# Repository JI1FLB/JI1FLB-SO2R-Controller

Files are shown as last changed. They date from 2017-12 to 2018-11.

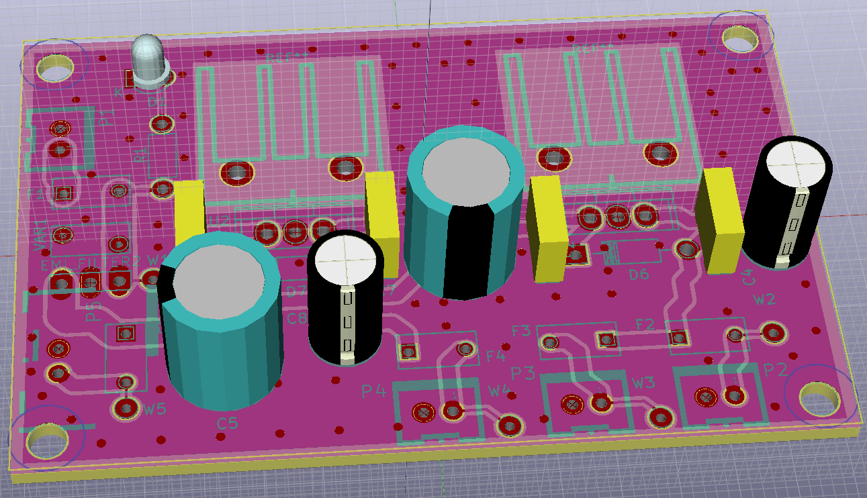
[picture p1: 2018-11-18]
CAD_data/SO2R-Power-unit-v0r0/SO2R-Power-unit-PCB-v0r0.png

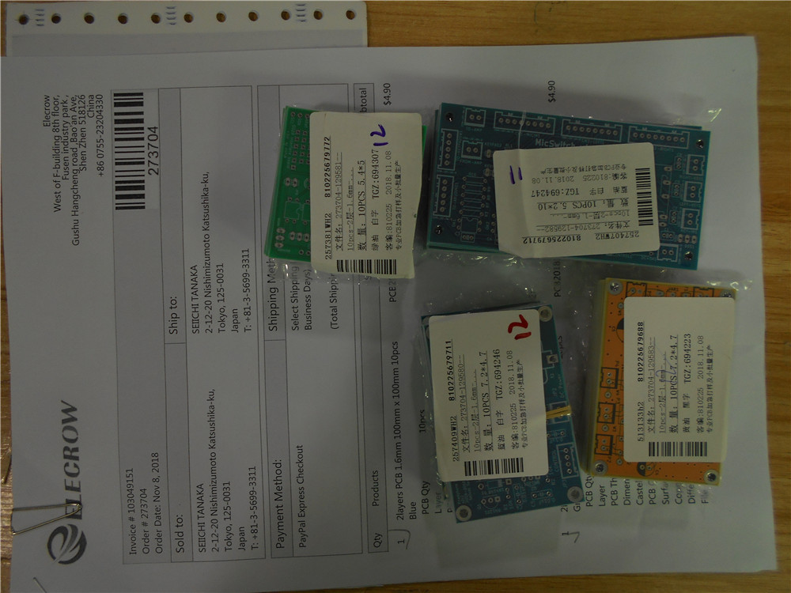
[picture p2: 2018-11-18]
CAD_data/MicSwitch-IF-v1r5/MicSwitch-IF-v1r5製造ファイル/273704.jpg

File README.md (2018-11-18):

# JI1FLB-SO2R-Controller

This JI1FLB SO2R box (controller) is a tool for amateur radio contest and works with OTRPS protocol.
This device controls two amateur radio rigs and is programmed with Arduino UNO sketch.
Hardware was composed of circuits that are easily available at electronic parts stores.
In addition, each circuit is designed to PCB to ensure ease of manufacture and product stability.

This JI1FLB　SO2R box (controller) provides software and hardware as freeware subject to non-commercial use.
Hardware PCB board is scheduled to provide KiCAD data subject to non-commercial use after completion of reprocessing.
I will supply the PCB to those who need it, with shipping fee and very cheap actual expenses. 
However, some consideration is required when installing some parts.

このJI1FLB　SO2Rボックス（コントローラ）は、アマチュア無線コンテスト用ツールでOTRPSプロトコロルで動作します。
この装置は、2台のアマチュア無線リグをコントロールするもので、ArduinoUNOのスケッチでプログラムされています。
ハードウェアは、電子パーツ店で容易に入手可能な部品で回路を構成しました。
また、各回路は、製作の容易性、製品の安定性を確保するため、PCB化を図っています。

このJI1FLB　SO2Rボックス（コントローラ）は、非商用利用を条件にソフトウェアとハードウェアをフリーウェアとして提供します。
ハードウェアのPCB基板は、KiCADデータを再作が完了後に、非商用利用を条件に提供する予定です。
私は、PCBを必要な方に、送料と非常に安価な実費で供給します。ただし、一部の部品を取り付け際に若干の考慮が必要です。

2018/11/18 Seiichi Tanaka 田中盛一

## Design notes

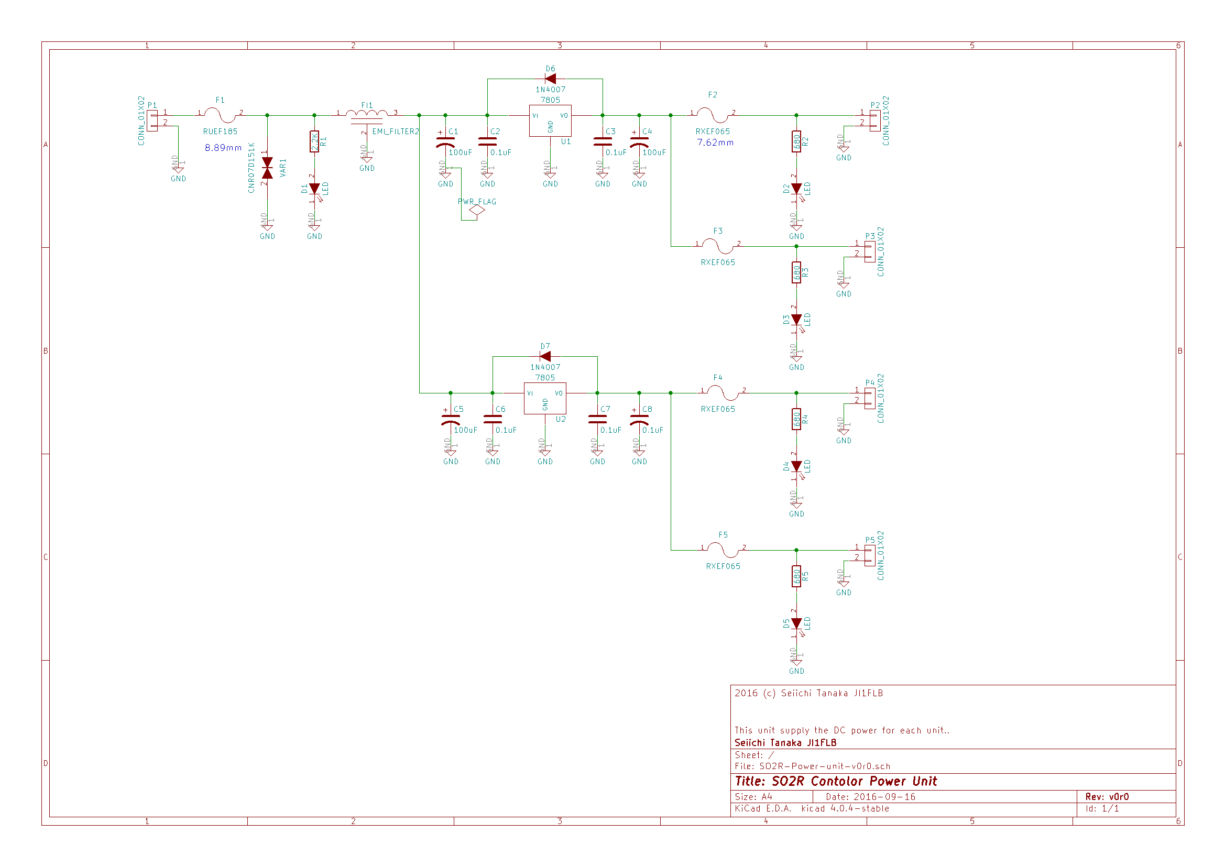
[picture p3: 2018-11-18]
CAD_data/SO2R-Power-unit-v0r0/SO2R-contolor-PU-v0r0.png

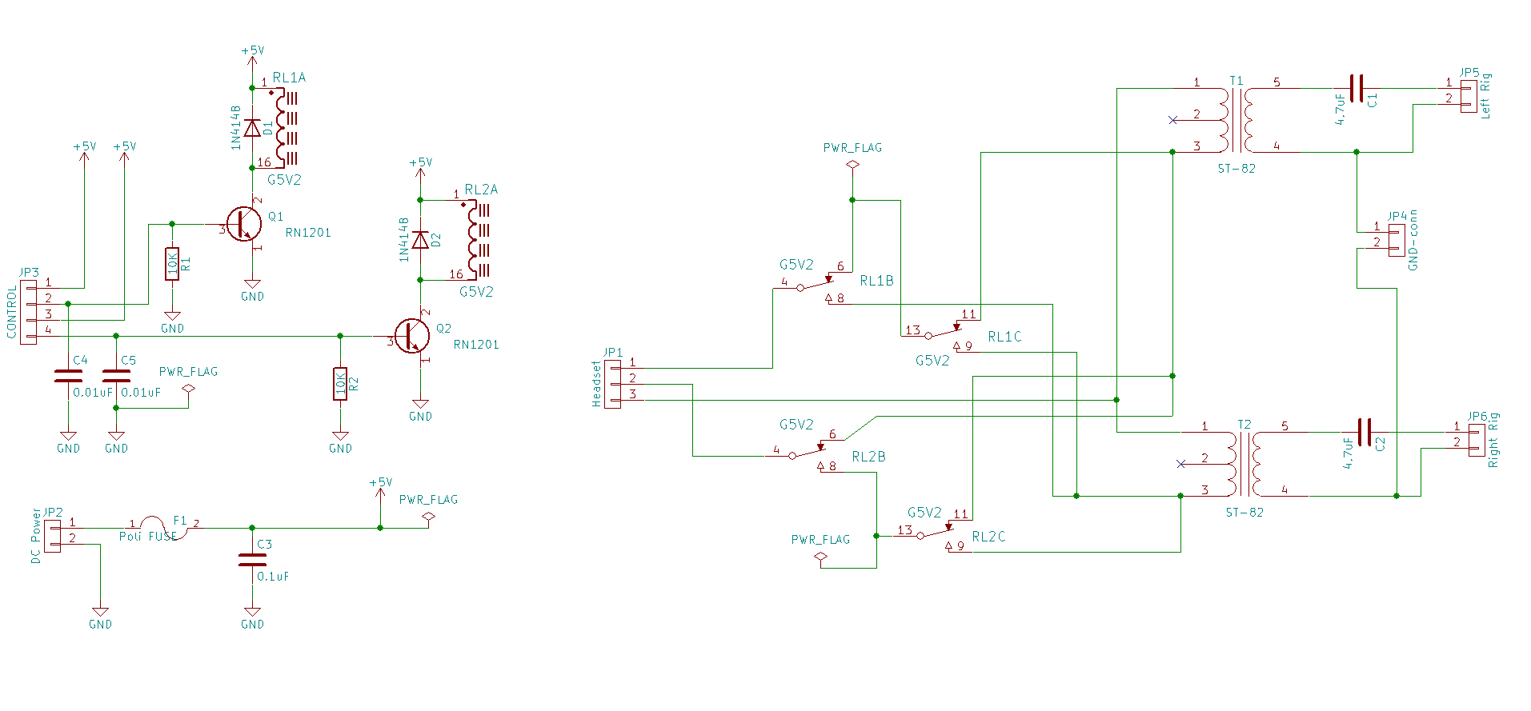
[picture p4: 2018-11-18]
CAD_data/Headphone-controler-v2r2/Headphone-controler-v2r2.png

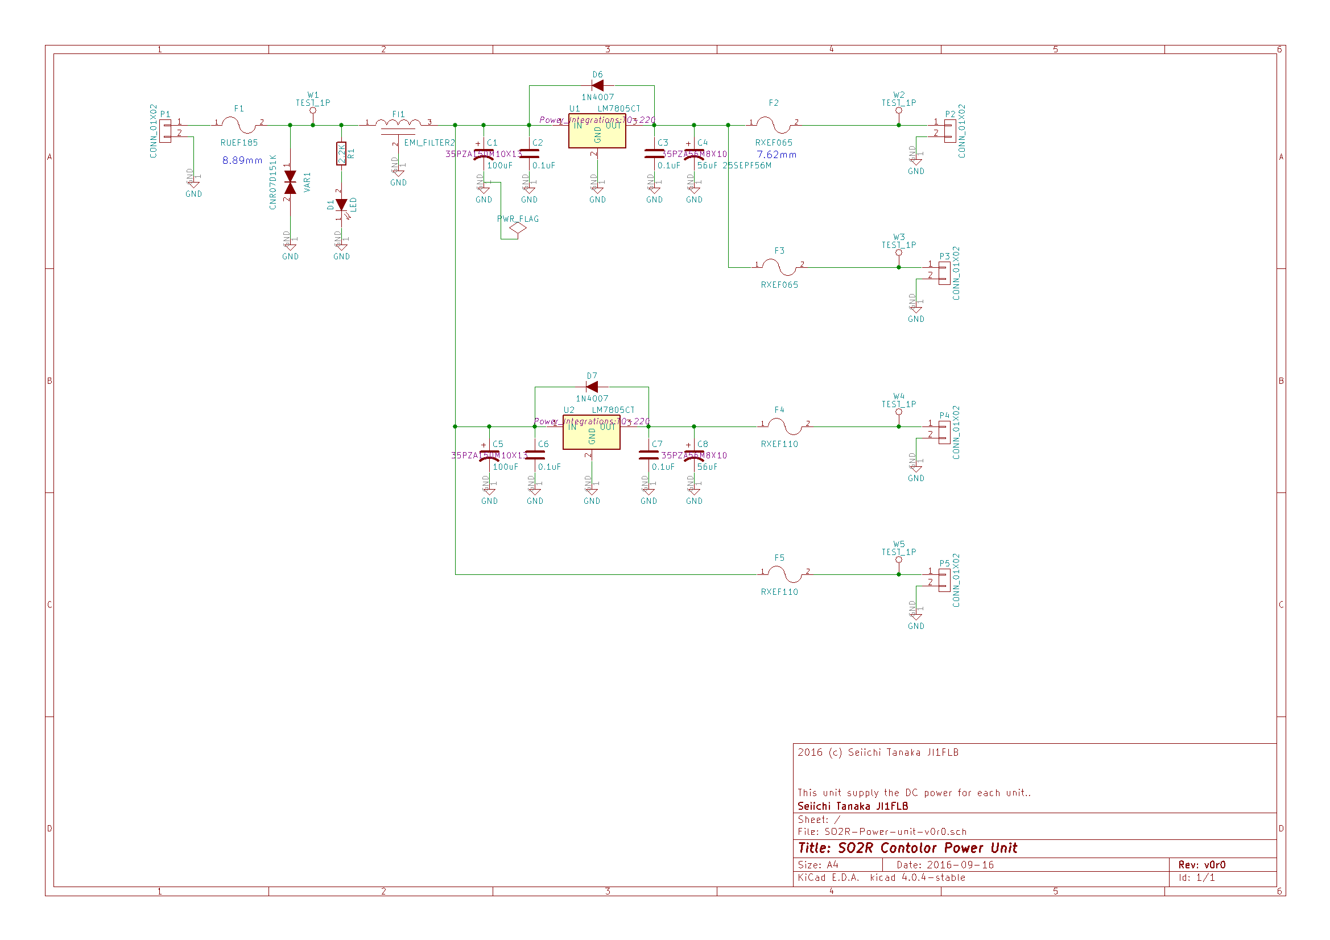
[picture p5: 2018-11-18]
CAD_data/SO2R-Power-unit-v0r0/SO2R-contolor-PU-v0r0-fixed.png

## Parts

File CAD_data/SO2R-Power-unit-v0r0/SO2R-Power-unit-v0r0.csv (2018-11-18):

ID | 参照記号 | パッケージ | 数 | 名称 | Supplier and ref
1 | C1,C5 | C_Radial_D10_L13_P5 | 2 | 100uF
2 | C2,C3,C6,C7 | C_Rect_L7_W2_P5 | 4 | 0.1uF
3 | D1 | LED-3MM | 1 | LED
4 | D6,D7 | Diode_DO-41_SOD81_Horizontal_RM10 | 2 | 1N4007
5 | F1 | C_Rect_L7_W3.5_P5 | 1 | RUEF185
6 | F2,F3 | C_Rect_L7_W3.5_P5 | 2 | RXEF065
7 | F4,F5 | C_Rect_L7_W3.5_P5 | 2 | RXEF110
8 | P1,P2,P3,P4,P5 | CON-JST-B02B-XASK-1 | 5 | CONN_01X02
9 | U1,U2 | TO-220 | 2 | LM7805CT
10 | W1,W2,W3,W4,W5 | SolderWirePad_single_0-8mmDrill | 5 | TEST_1P
11 | VAR1 | RV_Disc_D7_W3.4_P5 | 1 | CNR07D151K
12 | C4 | C_Radial_D6.3_L11.2_P2.5 | 1 | 56uF 25SEPF56M
13 | C8 | C_Radial_D6.3_L11.2_P2.5 | 1 | 56uF
14 | REF2,REF1 | Heatsink-16PB017 | 2 | Heatsink-16PB017
15 | R1 | Resistor_Horizontal_RM7mm | 1 | 2.2K
16 | FI1 | EMIFILTER | 1 | EMI_FILTER2
17 | REF**,REF**,REF**,REF** | MountingHole_3.2mm_M3_ISO7380_Pad | 4 | MountingHole_3.2mm_M3_ISO7380_Pad

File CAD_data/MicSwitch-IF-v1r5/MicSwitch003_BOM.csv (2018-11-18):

ID | 参�?記号 | パッケージ | 数 | 名称 | Supplier and ref
1 | D1,D2,D3,D4,D5 | DO35-7 | 5 | 1N4148
2 | DSS1 | EMIFILTER | 1 | 0.01u
3 | DC+5V1,CONTROL1,KEY-IN1,LEFT-KEY1,RIGHT-KEY1,TO-AMP,FROM-AMP | CON-JST-B02B-XASK-1 | 7 | CON-JST-XA-2
4 | Q1 | TO220BV | 1 | 2SK4017
5 | R1 | 0207_7 | 1 | 33
6 | R2 | 0207_7 | 1 | 10K
7 | RL1,RL2,RL3,RL4,RL5 | 351 | 5 | 941H-2C-5D
8 | CN1-MICIN1,CN2-RIGHT1,CN3-LEFT1 | CON-JST-B08B-XASK-1 | 3 | CON-JST-XA-8
9 | KEYPAD2,KEYPAD1 | 1X02 | 2 | PINHD-1X2
10 | R3,R4 | 0207_7 | 2 | 1.5k
11 | R5 | 0207_7 | 1 | 2.2k
12 | R6 | 0207_7 | 1 | 4.7k
13 | OK1,OK2,OK3,OK4 | DIL04 | 4 | TLP222AF
14 | TO-ARUDINO1,TO-KEYPADSW1 | CON-JST-B05B-XASK-1 | 2 | CON-JST-XA-5
15 | R7,R8,R9,R10 | 0207_7 | 4 | 480
16 | C1,C2,C3,C4,C5,C6,C7,C8,C9 | C025-030X050 | 9 | 0.01
17 | REF**,REF**,REF**,REF** | MountingHole_3.2mm_M3 | 4 | MountingHole_3.2mm_M3

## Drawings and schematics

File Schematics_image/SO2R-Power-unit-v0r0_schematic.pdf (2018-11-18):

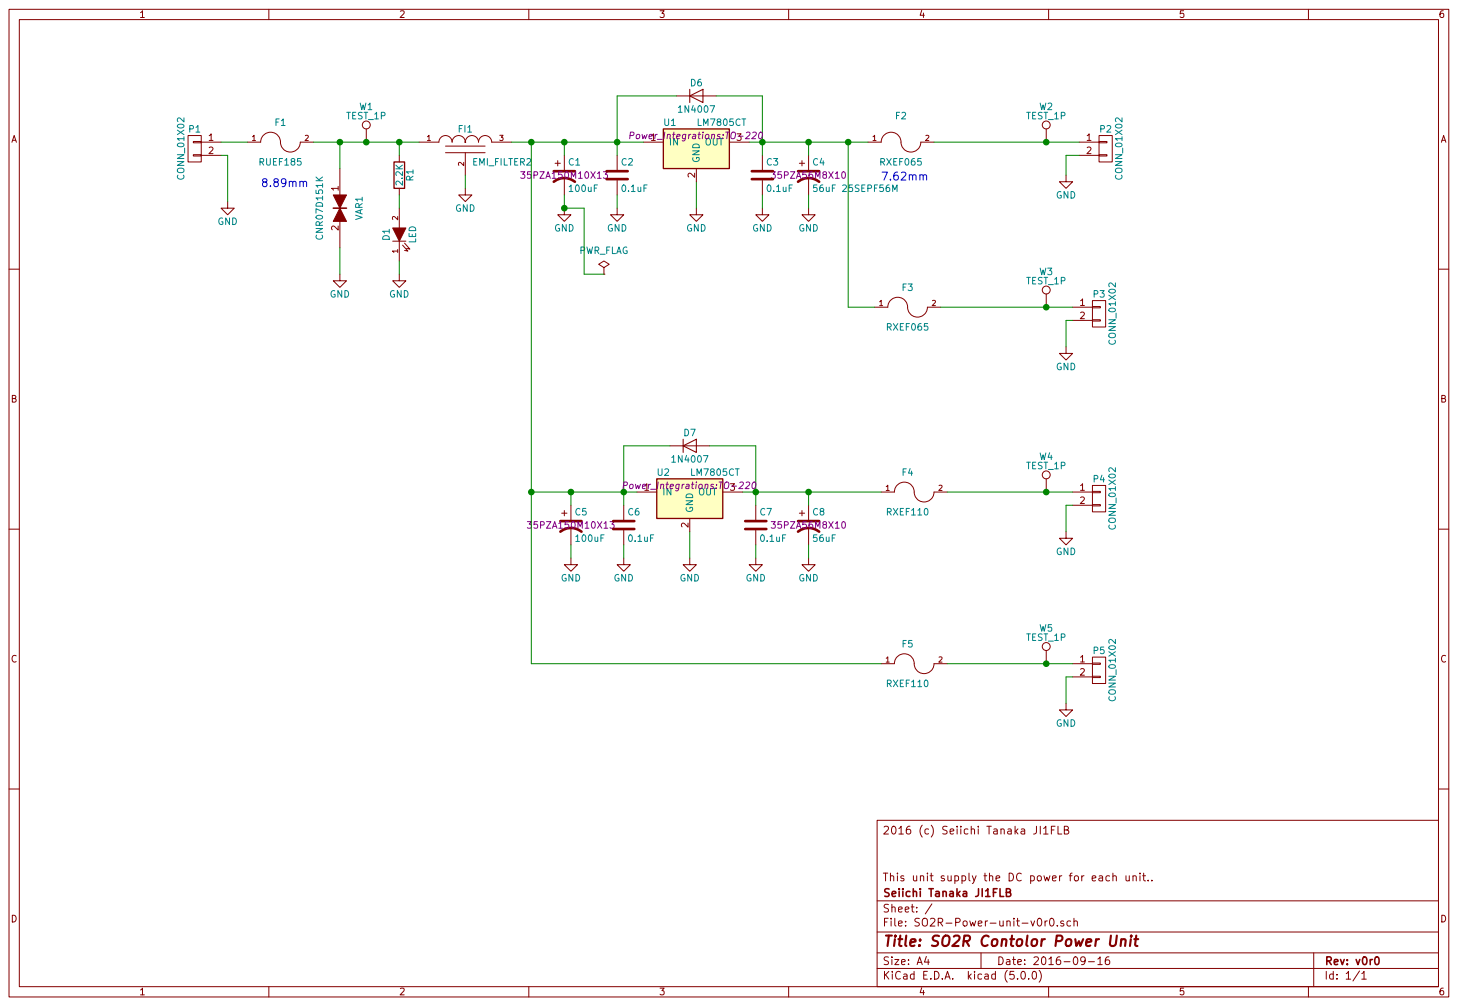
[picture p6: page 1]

1 2 D1 LED R1 2.2K GND GND GND GND GND GND GND GND GNDGND GND GND GND GND GND GND

This unit supply the DC power for each unit..
Id: 1/1 Title: SO2R Contolor Power Unit File: SO2R-Power-unit-v0r0.sch Sheet: / Seiichi Tanaka JI1FLB

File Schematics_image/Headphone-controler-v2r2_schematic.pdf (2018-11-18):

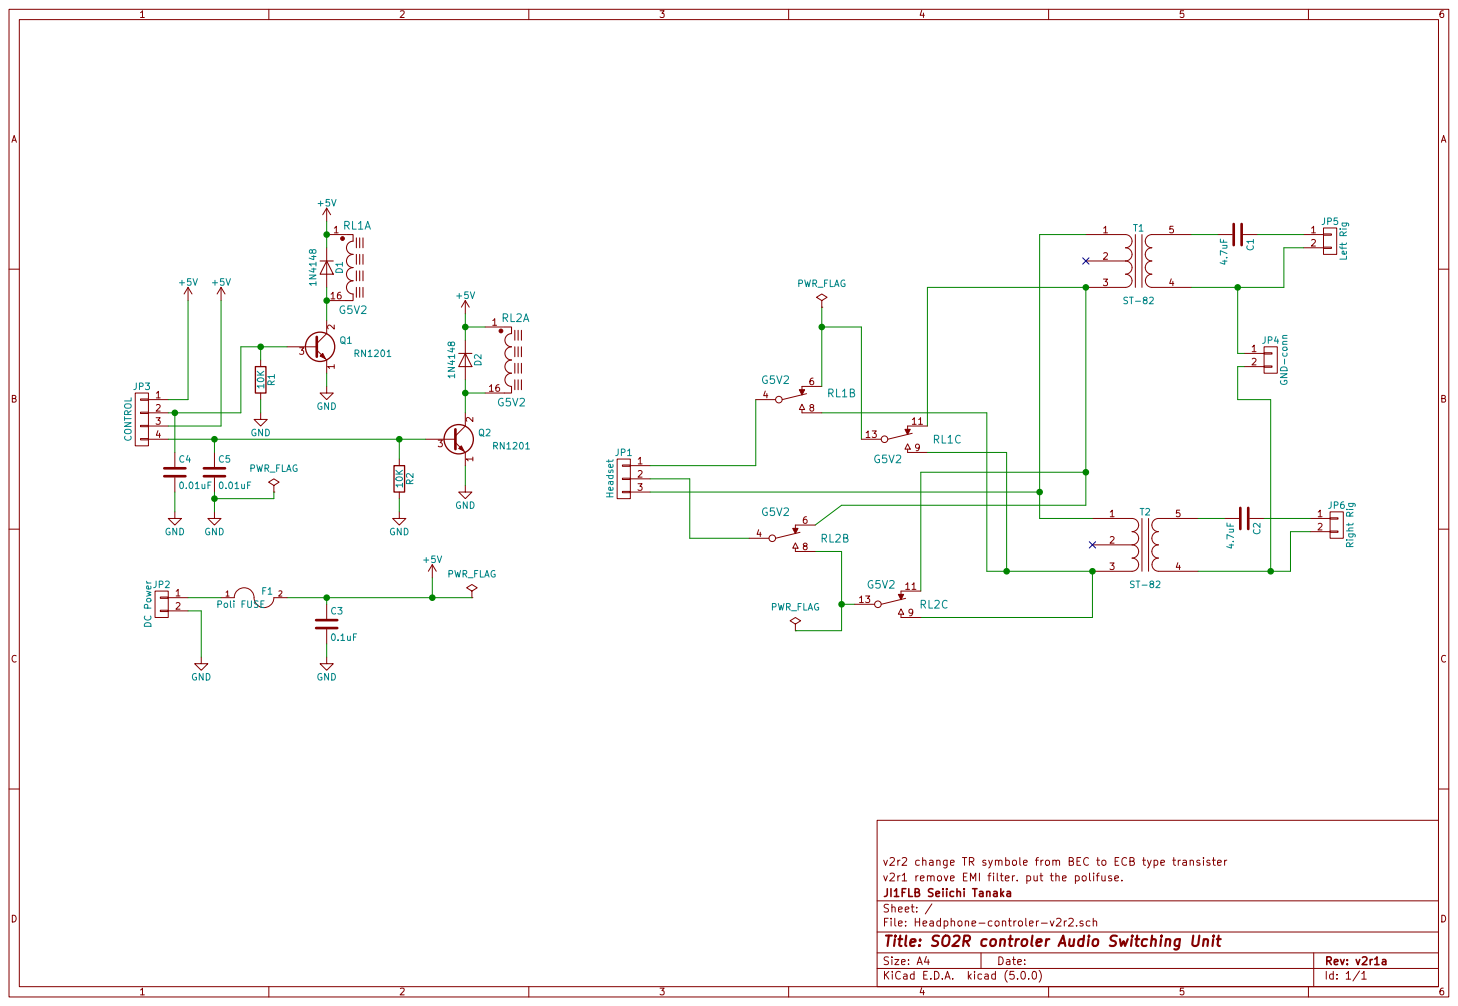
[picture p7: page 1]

v2r2 change TR symbole from BEC to ECB type transister
v2r1 remove EMI filter. put the polifuse.
File: Headphone-controler-v2r2.sch Sheet: / JI1FLB Seiichi Tanaka

Id: 1/1 Title: SO2R controler Audio Switching Unit

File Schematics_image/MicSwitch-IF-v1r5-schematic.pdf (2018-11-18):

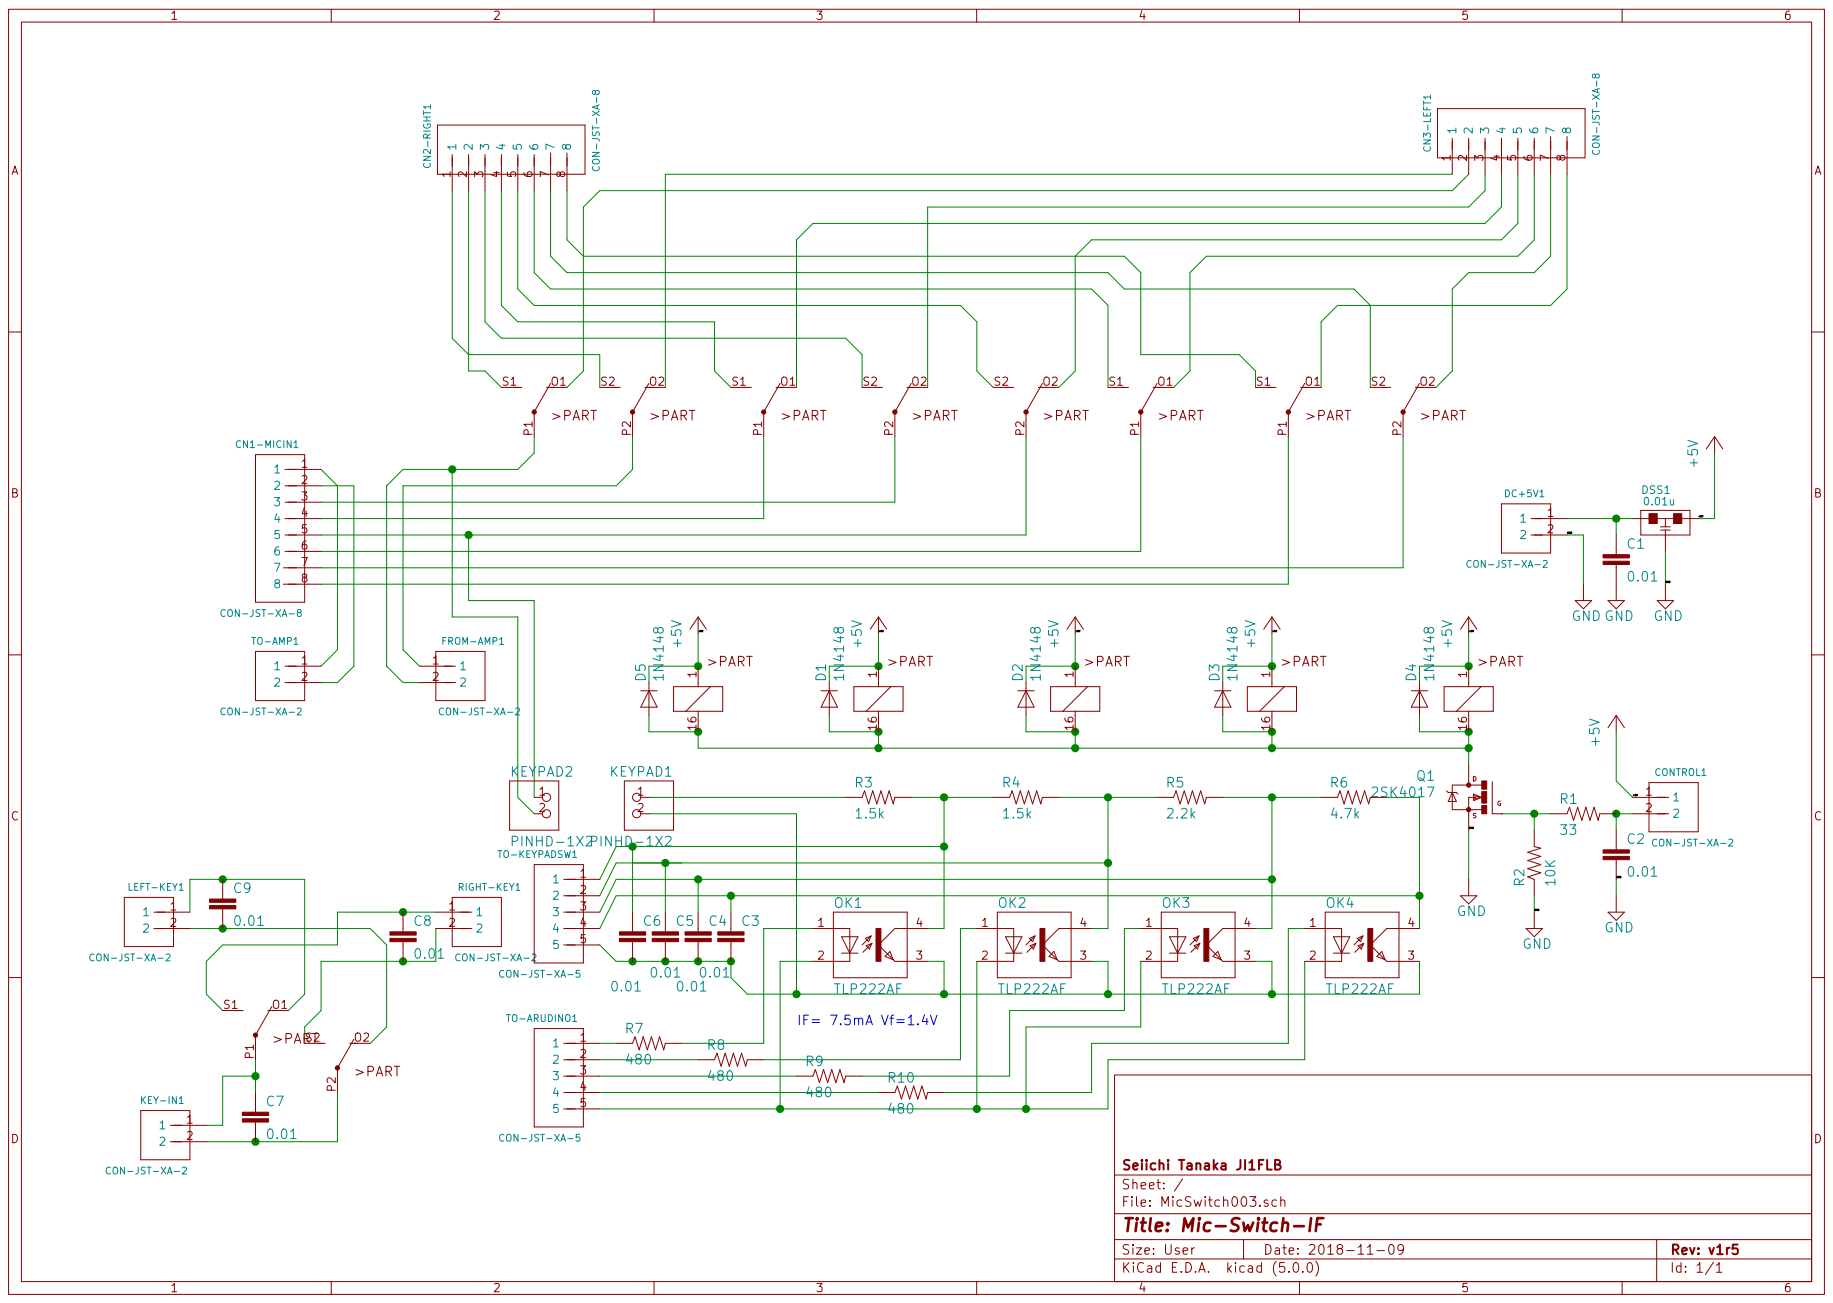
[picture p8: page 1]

File: MicSwitch003.sch Sheet: / Seiichi Tanaka JI1FLB

Id: 1/1 Title: Mic-Switch-IF

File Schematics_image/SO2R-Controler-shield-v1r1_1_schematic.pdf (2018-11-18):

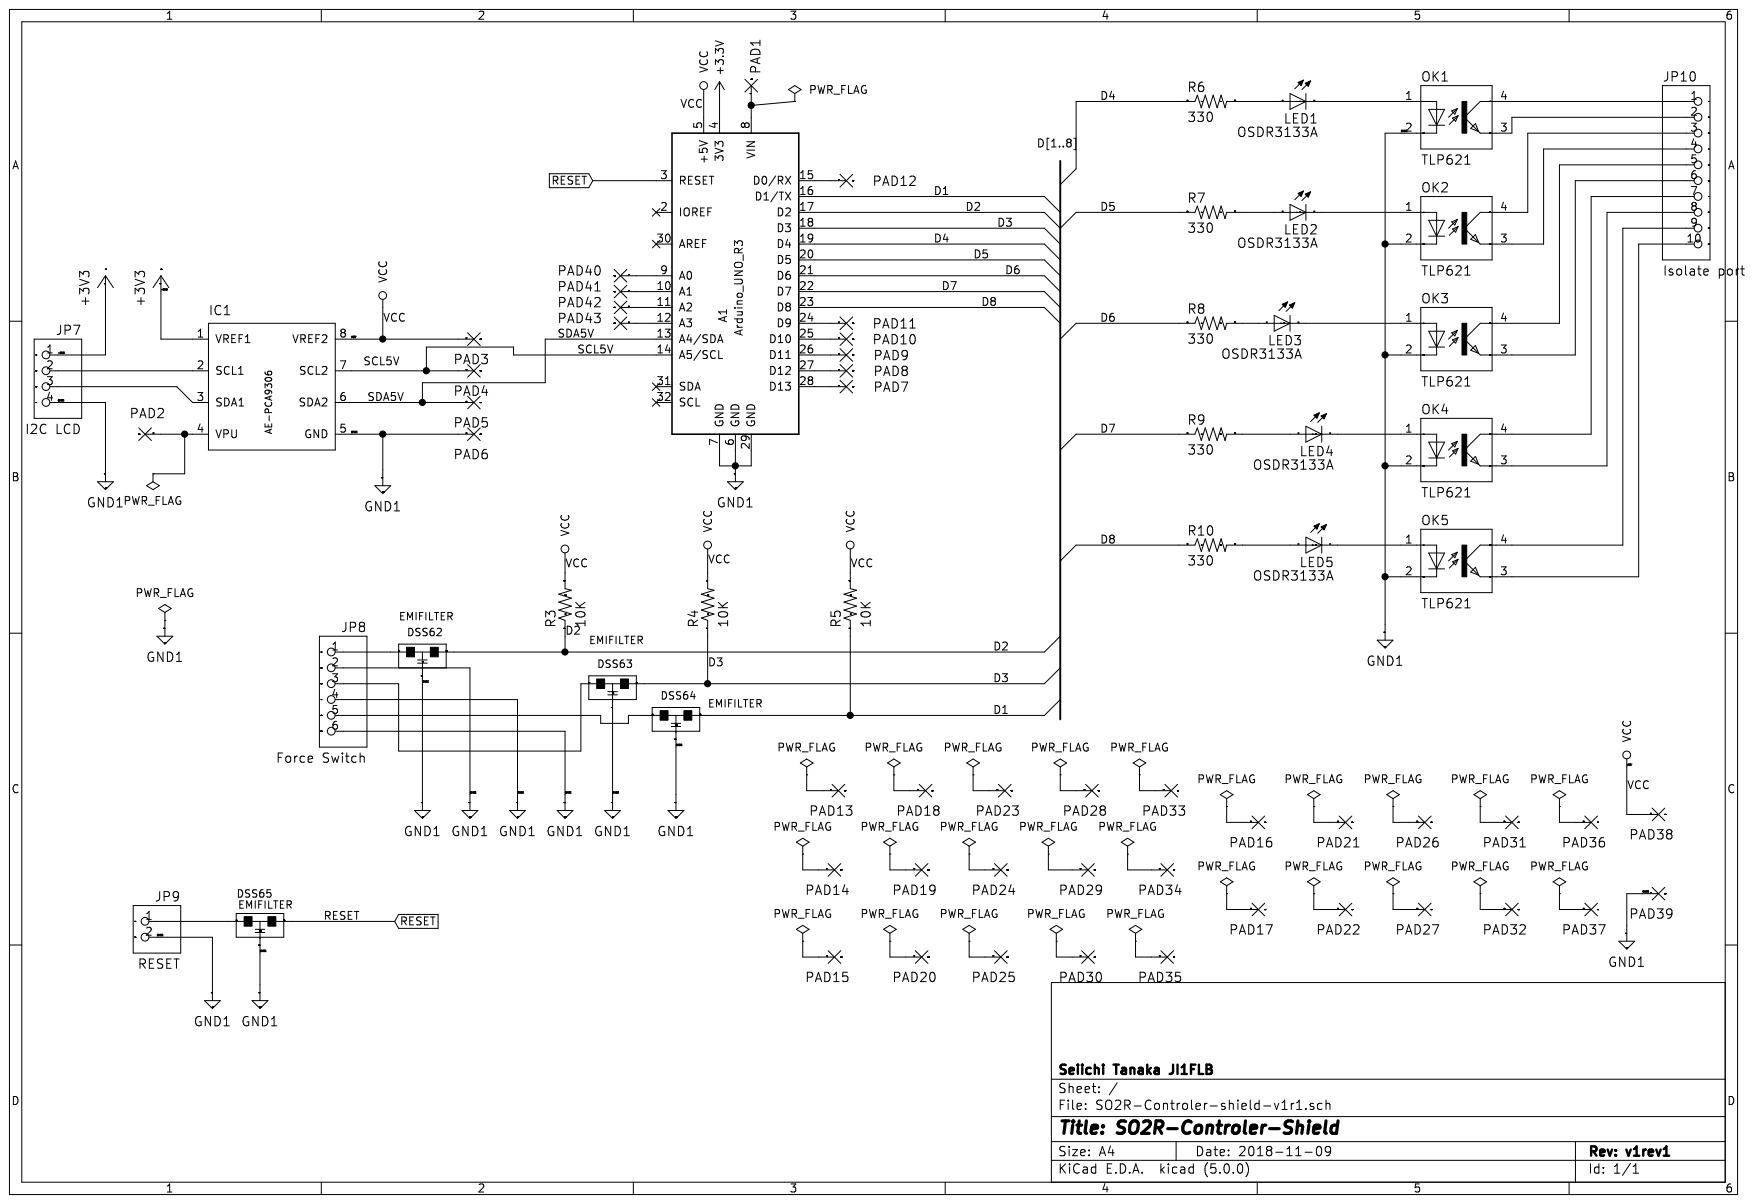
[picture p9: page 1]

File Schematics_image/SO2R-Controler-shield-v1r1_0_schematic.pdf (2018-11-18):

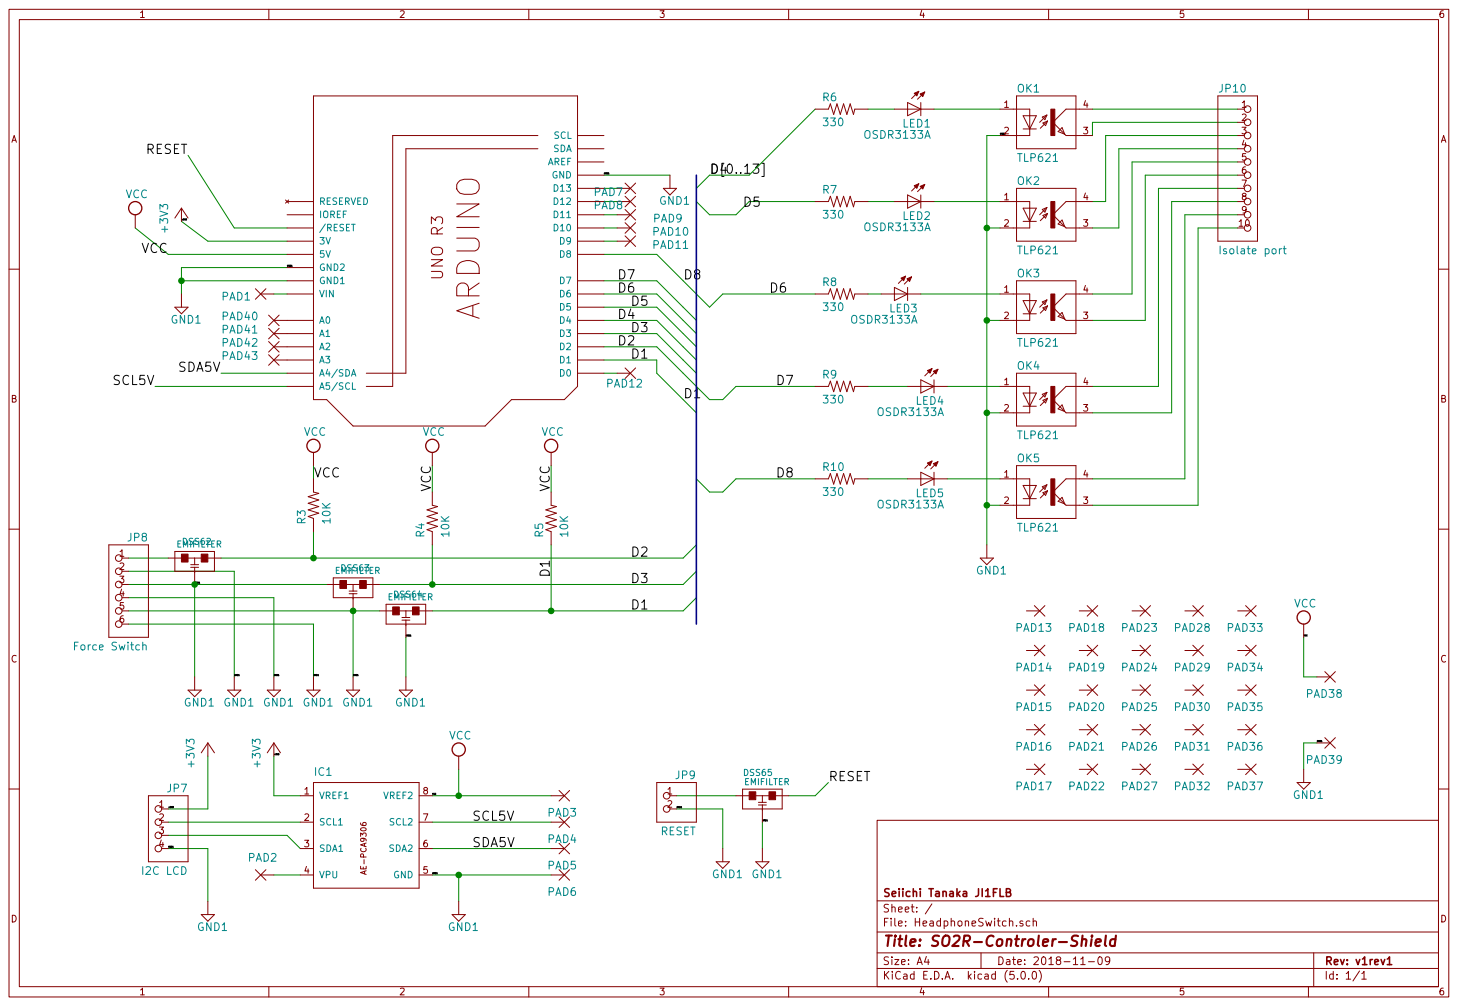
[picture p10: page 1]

File: HeadphoneSwitch.sch Sheet: / Seiichi Tanaka JI1FLB

Id: 1/1 Title: SO2R-Controler-Shield

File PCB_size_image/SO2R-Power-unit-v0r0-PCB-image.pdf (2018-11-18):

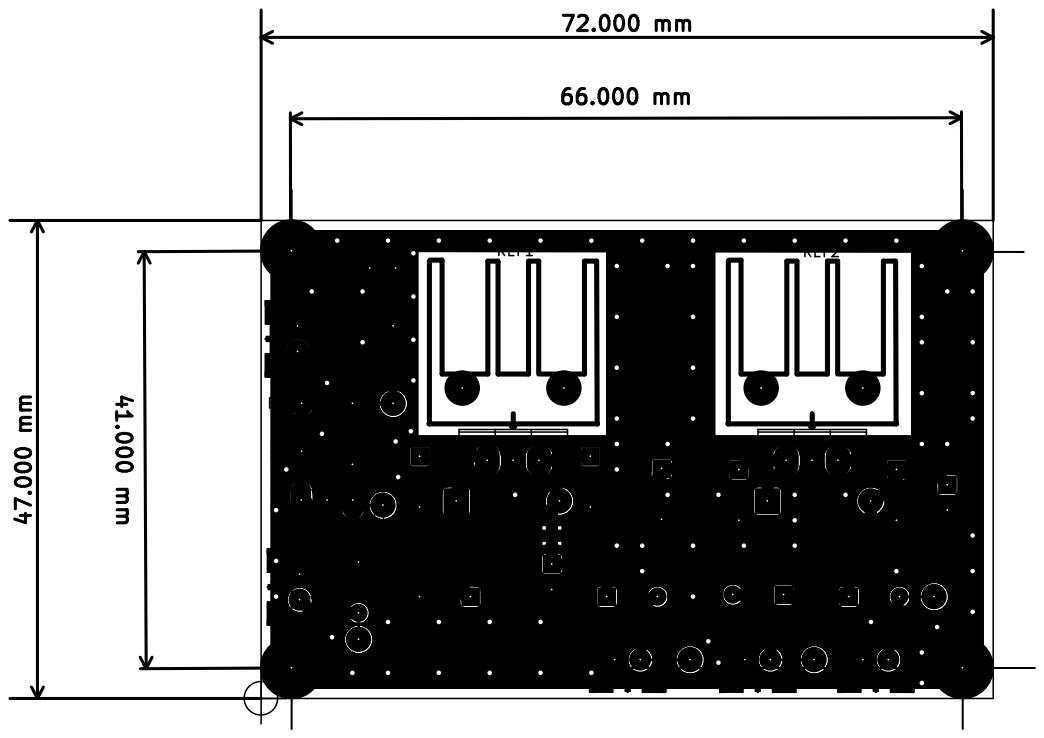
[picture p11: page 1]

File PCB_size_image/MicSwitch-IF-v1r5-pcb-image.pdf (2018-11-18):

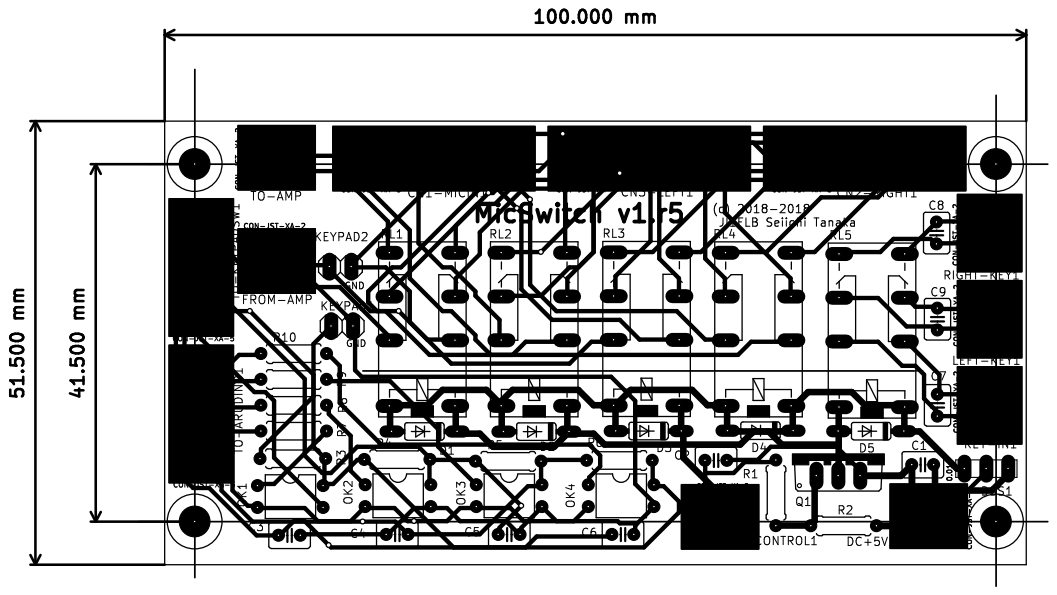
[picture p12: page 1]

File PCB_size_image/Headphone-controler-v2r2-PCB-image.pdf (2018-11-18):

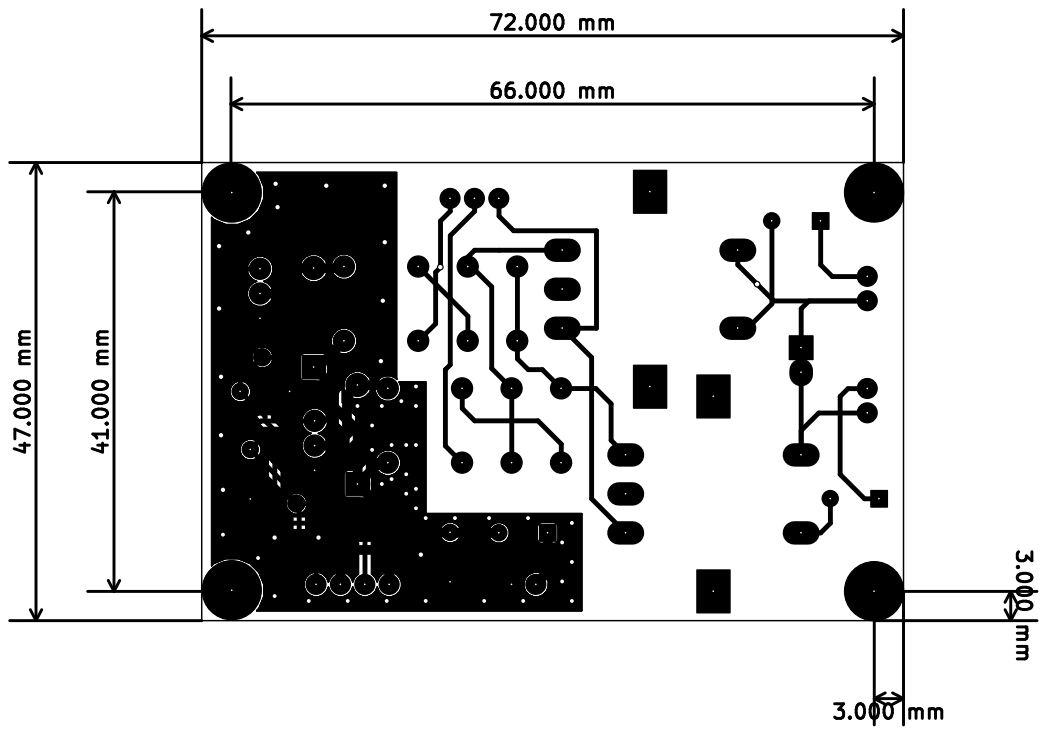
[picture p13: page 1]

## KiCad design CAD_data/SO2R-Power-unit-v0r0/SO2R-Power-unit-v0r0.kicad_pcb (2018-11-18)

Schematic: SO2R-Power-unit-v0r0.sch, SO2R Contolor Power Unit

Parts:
C1, C5: 100uF; C_Radial_D10_L13_P5
C2, C3, C6, C7: 0.1uF; C_Rect_L7_W2_P5
C4: 56uF 25SEPF56M; C_Radial_D6.3_L11.2_P2.5
C8: 56uF; C_Radial_D6.3_L11.2_P2.5
D1: LED; LED-3MM
D6, D7: 1N4007; Diode_DO-41_SOD81_Horizontal_RM10
F1: RUEF185; C_Rect_L7_W3.5_P5
F2, F3: RXEF065; C_Rect_L7_W3.5_P5
F4, F5: RXEF110; C_Rect_L7_W3.5_P5
FI1: EMI_FILTER2; EMIFILTER
P1, P2, P3, P4, P5: CONN_01X02; CON-JST-B02B-XASK-1
R1: 2.2K; Resistor_Horizontal_RM7mm
U1, U2: LM7805CT; TO-220
VAR1: CNR07D151K; RV_Disc_D7_W3.4_P5
W1, W2, W3, W4, W5: TEST_1P; SolderWirePad_single_0-8mmDrill

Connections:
GND: C1.2, C2.2, C3.2, C4.2, C5.2, C6.2, C7.2, C8.2, D1.1 (K), FI1.2 (GND), P1.2, P2.2, P3.2, P4.2, P5.2, U1.2 (GND), U2.2 (GND), VAR1.2
unnamed: C1.1, C2.1, C5.1, C6.1, D6.1, D7.1, F5.1, FI1.3 (VO), U1.1 (IN), U2.1 (IN)
unnamed: C3.1, C4.1, D6.2, F2.1, F3.1, U1.3 (OUT)
unnamed: C7.1, C8.1, D7.2, F4.1, U2.3 (OUT)
unnamed: D1.2 (A), R1.2
unnamed: F1.1, P1.1
unnamed: F1.2, FI1.1 (VI), R1.1, VAR1.1, W1.1
unnamed: F2.2, P2.1, W2.1
unnamed: F3.2, P3.1, W3.1
unnamed: F4.2, P4.1, W4.1
unnamed: F5.2, P5.1, W5.1

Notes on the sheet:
7.62mm
8.89mm

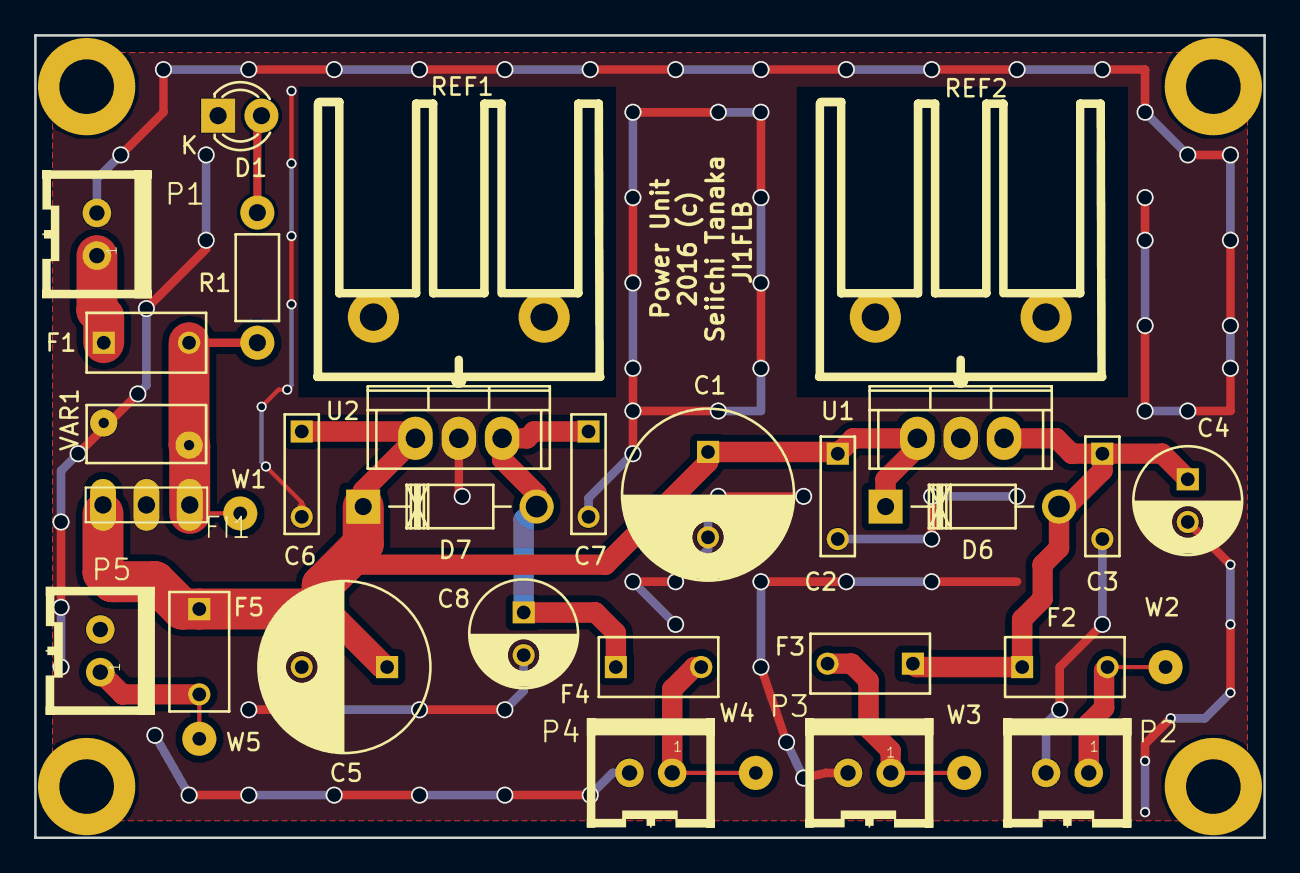
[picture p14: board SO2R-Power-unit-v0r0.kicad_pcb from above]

Board: 2 copper layers, 72.0 x 47.0 mm, 33 parts (0 on the bottom side), 11 nets.

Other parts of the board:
REF1, REF2: Heatsink-16PB017

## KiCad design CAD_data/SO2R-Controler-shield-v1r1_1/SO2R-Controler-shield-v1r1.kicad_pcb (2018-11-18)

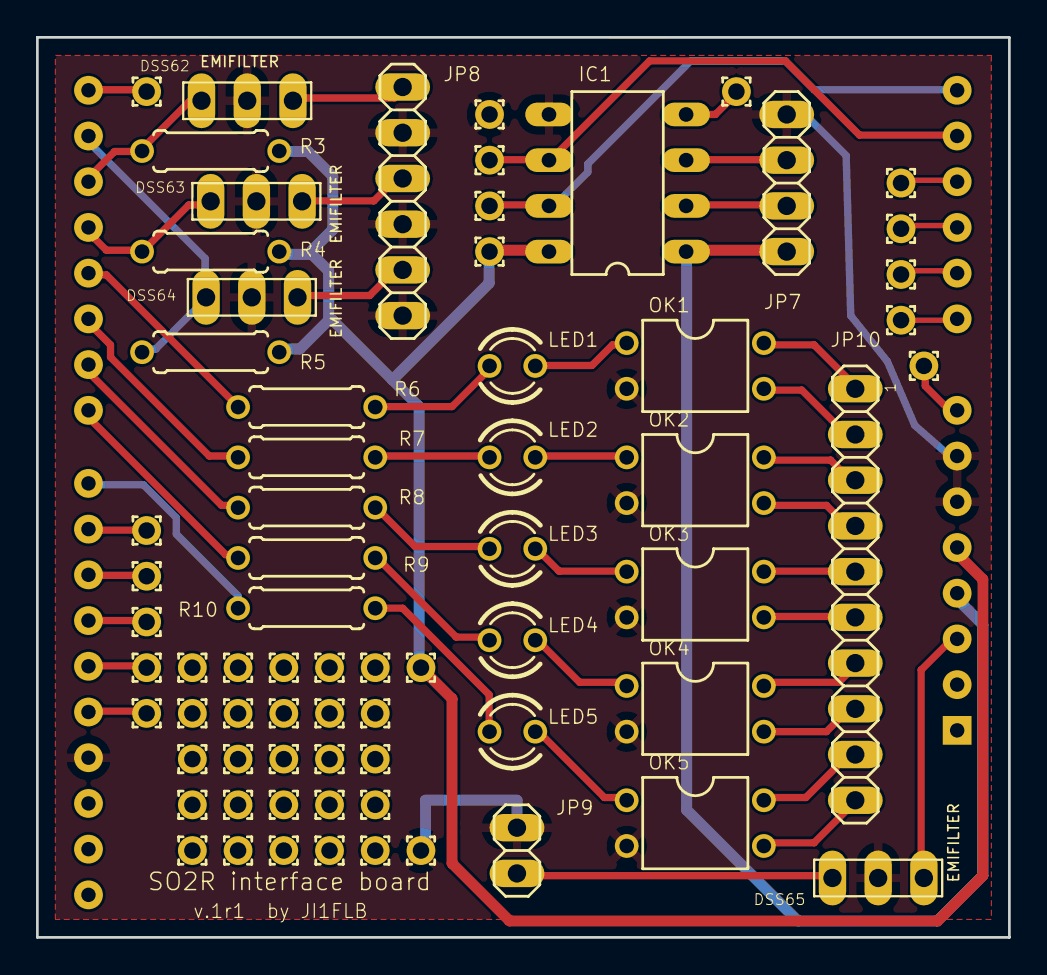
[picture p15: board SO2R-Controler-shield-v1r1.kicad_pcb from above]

Board: 2 copper layers, 54.0 x 50.0 mm, 71 parts (0 on the bottom side), 52 nets.

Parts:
A1: Arduino_UNO_R3
DSS62, DSS63, DSS64, DSS65: EMIFILTER
IC1: AE-PCA9306; DIL8
JP7: I2C LCD; 1X04
JP8: Force Switch; 1X06
JP9: RESET; 1X02
JP10: Isolate port; 1X10
LED1, LED2, LED3, LED4, LED5: OSDR3133A; LED3MM
OK1, OK2, OK3, OK4, OK5: TLP621; DIL04
PAD1, PAD2, PAD3, PAD4, PAD5, PAD6, PAD7, PAD8, PAD9, PAD10, PAD11, PAD12, PAD13, PAD14, PAD15, PAD16, PAD17, PAD18, PAD19, PAD20, PAD21, PAD22, PAD23, PAD24, PAD25, PAD26, PAD27, PAD28, PAD29, PAD30, PAD31, PAD32, PAD33, PAD34, PAD35, PAD36, PAD37, PAD38, PAD39, PAD40, PAD41, PAD42, PAD43: 1,6_0,9
R3, R4, R5: 10K; 0207_7
R6, R7, R8, R9, R10: 330; 0207_7

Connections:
+3V3: A1.4, IC1.1, JP7.1
/D1: A1.16, DSS64.3, R5.1
/D2: A1.17, DSS62.3, R3.1
/D3: A1.18, DSS63.3, R4.1
/D4: A1.19, R6.1
/D5: A1.20, R7.1
/D6: A1.21, R8.1
/D7: A1.22, R9.1
/D8: A1.23, R10.1
/SCL5V: A1.14, IC1.7, PAD4.1
/SDA5V: A1.13, IC1.6, PAD5.1
GND1: A1.6, A1.7, A1.29, DSS62.2, DSS63.2, DSS64.2, DSS65.2, IC1.5, JP7.4, JP8.2, JP8.4, JP8.6, JP9.2, OK1.2, OK2.2, OK3.2, OK4.2, OK5.2, PAD6.1, PAD39.1
unnamed: A1.8, PAD1.1
unnamed: A1.9, PAD40.1
unnamed: A1.10, PAD41.1
unnamed: A1.11, PAD42.1
unnamed: A1.12, PAD43.1
unnamed: A1.15, PAD12.1
unnamed: A1.24, PAD11.1
unnamed: A1.25, PAD10.1
unnamed: A1.26, PAD9.1
unnamed: A1.27, PAD8.1
unnamed: A1.28, PAD7.1
unnamed: DSS62.1, JP8.1
unnamed: DSS63.1, JP8.3
unnamed: DSS64.1, JP8.5
unnamed: DSS65.1, JP9.1
unnamed: IC1.2, JP7.2
unnamed: IC1.3, JP7.3
unnamed: IC1.4, PAD2.1
unnamed: JP10.1, OK1.4
unnamed: JP10.2, OK1.3
unnamed: JP10.3, OK2.4
unnamed: JP10.4, OK2.3
unnamed: JP10.5, OK3.4
unnamed: JP10.6, OK3.3
unnamed: JP10.7, OK4.4
unnamed: JP10.8, OK4.3
unnamed: JP10.9, OK5.4
unnamed: JP10.10, OK5.3
unnamed: LED1.A, R6.2
unnamed: LED1.K, OK1.1
unnamed: LED2.A, R7.2
unnamed: LED2.K, OK2.1
unnamed: LED3.A, R8.2
unnamed: LED3.K, OK3.1
unnamed: LED4.A, R9.2
unnamed: LED4.K, OK4.1
unnamed: LED5.A, R10.2
unnamed: LED5.K, OK5.1
RESET: A1.3, DSS65.3
VCC: A1.5, IC1.8, PAD3.1, PAD38.1, R3.2, R4.2, R5.2

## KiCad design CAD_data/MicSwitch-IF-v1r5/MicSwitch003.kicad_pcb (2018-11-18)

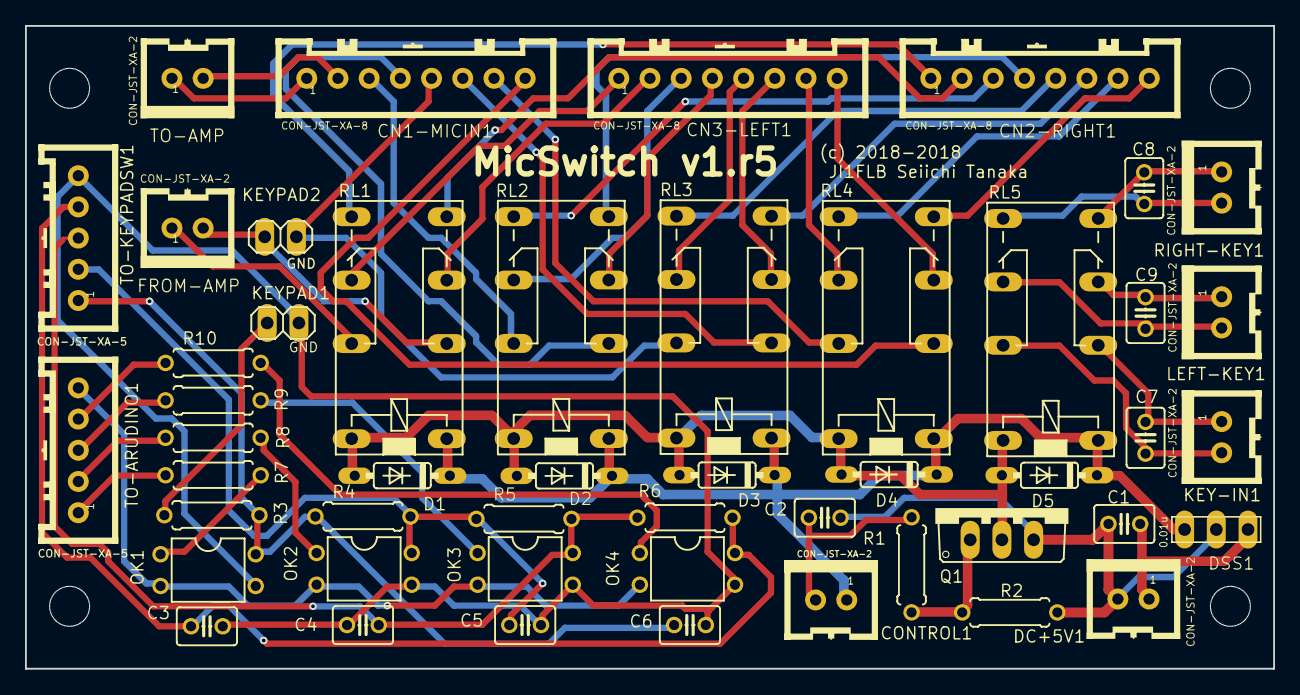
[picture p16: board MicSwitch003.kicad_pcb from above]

Board: 2 copper layers, 100.0 x 51.5 mm, 49 parts (0 on the bottom side), 53 nets.

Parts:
C1, C2, C3, C4, C5, C6, C7, C8, C9: 0.01; C025-030X050
CN1-MICIN1, CN2-RIGHT1, CN3-LEFT1: CON-JST-XA-8; CON-JST-B08B-XASK-1
CONTROL1: CON-JST-XA-2; CON-JST-B02B-XASK-1
D1, D2, D3, D4, D5: 1N4148; DO35-7
DC+5V1: CON-JST-XA-2; CON-JST-B02B-XASK-1
DSS1: 0.01u; EMIFILTER
FROM-AMP: CON-JST-XA-2; CON-JST-B02B-XASK-1
KEY-IN1: CON-JST-XA-2; CON-JST-B02B-XASK-1
KEYPAD1, KEYPAD2: PINHD-1X2; 1X02
LEFT-KEY1: CON-JST-XA-2; CON-JST-B02B-XASK-1
OK1, OK2, OK3, OK4: TLP222AF; DIL04
Q1: 2SK4017; TO220BV
R1: 33; 0207_7
R2: 10K; 0207_7
R3, R4: 1.5k; 0207_7
R5: 2.2k; 0207_7
R6: 4.7k; 0207_7
R7, R8, R9, R10: 480; 0207_7
RIGHT-KEY1: CON-JST-XA-2; CON-JST-B02B-XASK-1
RL1, RL2, RL3, RL4, RL5: 941H-2C-5D; 351
TO-AMP: CON-JST-XA-2; CON-JST-B02B-XASK-1
TO-ARUDINO1: CON-JST-XA-5; CON-JST-B05B-XASK-1
TO-KEYPADSW1: CON-JST-XA-5; CON-JST-B05B-XASK-1

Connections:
+5V: CONTROL1.1, D1.C, D2.C, D3.C, D4.C, D5.C, DSS1.3, RL1.1, RL2.1, RL3.1, RL4.1, RL5.1
GND: C1.2, C2.2, DC+5V1.2, DSS1.2, Q1.S, R2.1
unnamed: C1.1, DC+5V1.1, DSS1.1
unnamed: C2.1, CONTROL1.2, R1.2
unnamed: C3.1, OK4.4, R6.2, TO-KEYPADSW1.4
unnamed: C3.2, C4.2, C5.2, C6.2, KEYPAD1.2, OK1.3, OK2.3, OK3.3, OK4.3, TO-KEYPADSW1.5
unnamed: C4.1, OK3.4, R5.2, R6.1, TO-KEYPADSW1.3
unnamed: C5.1, OK2.4, R4.2, R5.1, TO-KEYPADSW1.2
unnamed: C6.1, OK1.4, R3.2, R4.1, TO-KEYPADSW1.1
unnamed: C7.1, KEY-IN1.1, RL5.P1
unnamed: C7.2, KEY-IN1.2, RL5.P2
unnamed: C8.1, RIGHT-KEY1.1, RL5.S1
unnamed: C8.2, RIGHT-KEY1.2, RL5.S2
unnamed: C9.1, LEFT-KEY1.1, RL5.O1
unnamed: C9.2, LEFT-KEY1.2, RL5.O2
unnamed: CN1-MICIN1.1, TO-AMP.1
unnamed: CN1-MICIN1.2, TO-AMP.2
unnamed: CN1-MICIN1.3, RL2.P2
unnamed: CN1-MICIN1.4, RL2.P1
unnamed: CN1-MICIN1.5, KEYPAD2.1, RL3.P2
unnamed: CN1-MICIN1.6, RL3.P1
unnamed: CN1-MICIN1.7, RL4.P2
unnamed: CN1-MICIN1.8, RL4.P1
unnamed: CN2-RIGHT1.1, RL1.S2
unnamed: CN2-RIGHT1.2, RL1.S1
unnamed: CN2-RIGHT1.3, RL2.S2
unnamed: CN2-RIGHT1.4, RL2.S1
unnamed: CN2-RIGHT1.5, RL3.S2
unnamed: CN2-RIGHT1.6, RL3.S1
unnamed: CN2-RIGHT1.7, RL4.S2
unnamed: CN2-RIGHT1.8, RL4.S1
unnamed: CN3-LEFT1.1, RL1.O2
unnamed: CN3-LEFT1.2, RL1.O1
unnamed: CN3-LEFT1.3, RL2.O2
unnamed: CN3-LEFT1.4, RL2.O1
unnamed: CN3-LEFT1.5, RL3.O2
unnamed: CN3-LEFT1.6, RL3.O1
unnamed: CN3-LEFT1.7, RL4.O2
unnamed: CN3-LEFT1.8, RL4.O1
unnamed: D1.A, D2.A, D3.A, D4.A, D5.A, Q1.D, RL1.16, RL2.16, RL3.16, RL4.16, RL5.16
unnamed: FROM-AMP.1, RL1.P2
unnamed: FROM-AMP.2, KEYPAD2.2, RL1.P1
unnamed: KEYPAD1.1, R3.1
unnamed: OK1.1, R7.2
unnamed: OK1.2, OK2.2, OK3.2, OK4.2, TO-ARUDINO1.5
unnamed: OK2.1, R8.2
unnamed: OK3.1, R9.2
unnamed: OK4.1, R10.2
unnamed: Q1.G, R1.1, R2.2
unnamed: R7.1, TO-ARUDINO1.1
unnamed: R8.1, TO-ARUDINO1.2
unnamed: R9.1, TO-ARUDINO1.3
unnamed: R10.1, TO-ARUDINO1.4

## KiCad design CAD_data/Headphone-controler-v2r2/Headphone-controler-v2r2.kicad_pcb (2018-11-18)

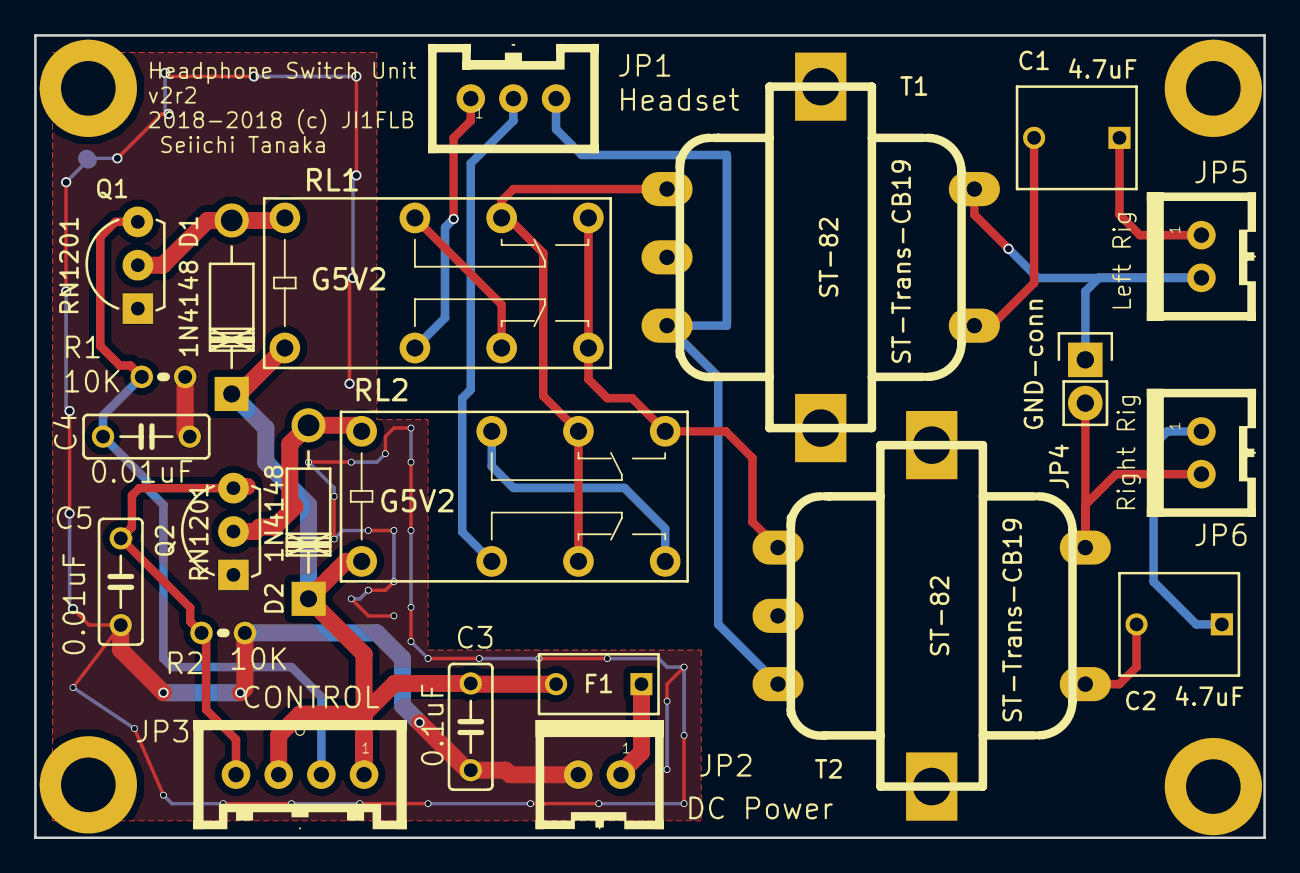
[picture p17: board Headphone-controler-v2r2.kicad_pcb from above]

Board: 2 copper layers, 72.0 x 47.0 mm, 22 parts (0 on the bottom side), 20 nets.

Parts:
C1, C2: 4.7uF; C_Rect_L7_W6_P5
C3: 0.1uF; C050-025X075
C4, C5: 0.01uF; C050-025X075
D1, D2: 1N4148; Diode_DO-41_SOD81_Horizontal_RM10
F1: Poli FUSE; C_Rect_L7_W3.5_P5
JP1: Headset; CON-JST-B03B-XASK-1
JP2: DC Power; CON-JST-B02B-XASK-1
JP3: CONTROL; CON-JST-B04B-XASK-1
JP4: GND-conn; Pin_Header_Straight_1x02
JP5: Left Rig; CON-JST-B02B-XASK-1
JP6: Right Rig; CON-JST-B02B-XASK-1
Q1, Q2: RN1201; 2SC1815GR
R1, R2: 10K; 0204V
RL1, RL2: G5V2; G5V-2
T1, T2: ST-82; ST-Trans-CB19

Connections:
+5V: C3.1, D1.1, D2.1, F1.2, JP3.1, JP3.3, RL1.1, RL2.1
GND: C3.2, C4.2, C5.2, JP2.2, Q1.1, Q2.1, R1.2, R2.2
unnamed: C1.1, JP5.1
unnamed: C1.2, T1.5
unnamed: C2.1, JP6.1
unnamed: C2.2, T2.5
unnamed: C4.1, JP3.2, Q1.3, R1.1
unnamed: C5.1, JP3.4, Q2.3, R2.1
unnamed: D1.2, Q1.2, RL1.16
unnamed: D2.2, Q2.2, RL2.16
unnamed: F1.1, JP2.1
unnamed: JP1.1, RL1.4
unnamed: JP1.2, RL2.4
unnamed: JP1.3, T1.1, T2.1
unnamed: JP4.1, JP5.2, T1.4
unnamed: JP4.2, JP6.2, T2.4
unnamed: RL1.8, RL1.9, RL2.9, T2.3
unnamed: RL1.11, RL2.6, RL2.11, T1.3
unnamed: RL1.6, RL1.13
unnamed: RL2.8, RL2.13

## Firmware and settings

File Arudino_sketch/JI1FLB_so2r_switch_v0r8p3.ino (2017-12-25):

/*
JI1FLB SO2Rコントローラ Copyright (C) JI1FLB Seiichi Tanaka 2017/06/10
Licens: This sketch is a freeware based on GNU GENERAL PUBLIC LICENS Version 3.
Last Modify:2017/06/10 18:24
Version：0版
Revise ：8版
Patch ： 3回目
Protocol ： OTRSP http://www.k1xm.org/OTRSP/OTRSP_Protocol.pdf
History of Features which is appending.：
	・マイク切替
	・PTT切替
	・ヘッドホーン切替
	・CWポート切替
	・Ant Band情報(AUX1対応のみ)		v0r2p6
	・ボイスメモリ対応機能の検証		v0r6p1
	・QueueListのQUEUEを利用廃止		v0r6p1
	・Query系に？のみ受信時の処理		v0r6p1
	・手動切替（強制リグロック機能）	v0r6p22
	・プッシュボタン動作でリグのロックをOn/Offする
			注：外部割込み(Int.0,Int.1)を利用し、プッシュボタン動作でリグのロックをOn/Offする機能はFS
	・OTRSP buffer Clear feature	V0r6p23
		OTRSP関連のSerial通信のバッファと、OTRSPcommandバッファをクリアする機能
	・I2C　LCDディスプレー表示機能		v0r7p0
	・手動切替モード(Face switch feature)	V0r8p0

*/


/* Histoy of Modify

yyyy/mm/dd
	ヘッドホーン動作マトリックスに合わせて、ディジタルポート動作を変更
2014年9月2日 8:28:03
	一部変数名のアンダバー削除、LockingHandling()の追加
2014年9月14日17:17:12
	ソフトウェア構造を大幅に変更
	各ペリフェイラルからの情報を受け取るルーチンに変更
2016/12/10 v0r8p0 
	Face Switch featuresのソフトウェア変更
	ArudinoUNOのポートアサインメントの整理
2017年6月10日18:17:43 v0r8p3
	command_handling(),aux1_output_handling(),LcdDisplayLockedSo2r(),LcdDisplaySo2r()のダイナミックステップ改善

*/


/* N1MM OTRSP　キャプチャ結果　2013/11/09

\ key	RXx
@ key	RXxS
Pause key	TXx RXx or TXx RXxS
Ctrl+Left arrow  key	Leftに設定したリグ　TXx RXx or TXx RXxS
Ctrl+Right arrow key	Rightに設定したリグ　TXx RXx or TXx RXxS
Band change
	antenna tabに設定されている場合		AUXx0n
	antenna tabに設定されていない場合	AUXx-01
判ったこと
	受信時のリバース機能はサポートされいない模様
	AUXは　AUXxnnでAntenna Tabのコードが一桁の場合、nnの二けた目を0でパティングする。
	Ctrl+PageUP/PageDown 時は、バンド情報が即、通知される。
	Rigでバンドチェンジした場合には、バンド情報がSO2Rデバイスに通知されるまで、少し時間がかかる。

*/

//------------------------------------------------------------------

#include <Wire.h>			// Arduino IDE のI2Cライブラリ
#include <LcdCore.h>		// LCDコアライブラリ
#include <LCD_ACM1602NI.h>	// 秋月I2C液晶用のI/Oライブラリ
LCD_ACM1602NI lcd(0xa0);	// 0xa0はI2Cアドレス

//-------------------------------------------------------------------
//                   0123456789012345
#define message00	"JI1FLB SO2R Box "
#define message01	"<Rig- L><Rig- R>"
#define message02	"Left      Locked"
#define message03	"Right     Locked"
#define message04	"--------        "
#define message05	"        --------"
#define message06	"--------"
#define message07	"Rx Tx   --------"
#define message08	"Rx  "
#define message09	"RxS "
#define message10	"RxR "
#define message11	"Tx  "
#define message12	"-------- Rx Tx  "
#define message13	"Rx Tx  Rx       "
#define message14	"Rx     Rx   Tx  "
#define message15	" Locked --------"
#define message16	"-------  Locked "
#define message17	"----"
#define message18	"Left  ST  Locked"
#define message19	"Right ST  Locked"


//-------------------------------------------------------------------------------
// 変数の定義
//


	int		Rig1PushSwStatus ;
	int		Rig2PushSwStatus ;
	int		StereoPushSwStatus ;

	unsigned	long	GuardTime= 250 ;
	unsigned	long	NowTimeRig1 ;
	unsigned	long	NowTimeRig2 ;
	unsigned	long	NowTimeStereo ;
	unsigned	long	OldTimeRig1 ;
	unsigned	long	OldTimeRig2 ;
	unsigned	long	OldTimeStereo ;
	unsigned	long	TimeRig1 ;
	unsigned	long	TimeRig2 ;
	unsigned	long	TimeStereo ;

	boolean	OccuredLocking ;
	boolean	Rig1IsLocked ;
	boolean	Rig2IsLocked ;
	boolean	StereoIsLocked ;
	boolean	RigLockedStatus ;
	boolean	OldRigLockedStatus ;


// for generel Constants
	String	OTRSPcommand ;
	String	RxStatus ;
	String	TxStatus ;
	String	OldRxStatus ;
	String	OldTxStatus ;
	String	AuxStatus ;
	String	DVKStatus ;
	boolean	Recived ;

// Definition of constants and pin numbers
// Constants for Locked Rig

	const	int		Rig1PushSwPort = 2 ;	// Constants for Locked Rig
	const	int		Rig2PushSwPort = 3 ;	// Constants for Locked Rig
	const	int		StereoPushSwPort = 1 ;	// Constants for Locked Rig

	const	int		RX_cont_RL1 = 4 ;
	const	int		RX_cont_RL2 = 5 ;
	const	int		TX_sw_RL = 6 ;
	const	int		CW_padle = 7 ;

	const	int		AUX0_1 = 8 ;
	const	int		AUX0_2  = 9;
	const	int		AUX0_4  = 10 ;
	const	int		AUX0_8  = 11 ;

	const	int		Reverse = 12 ;
	const	int		Stereo = 13 ;
	
	const	int		DVKm1 = 8 ;
	const	int		DVKm2 = 9 ;
	const	int		DVKm3 = 10 ;
	const	int		DVKm4 = 11 ;
	const	int		OTRSPlength = 17;
	
// Constants for FW & System Name
	const	String	FW	 =	 "0.8.3" ;
	const	String	SO2R_name = "JI1FLB SO2R Controler" ;


//--------------------------------------
//
// the setup routine run
//
//--------------------------------------



void setup() {

  // initialize the digital pin as an output.
	
	pinMode( RX_cont_RL1 , OUTPUT ) ;
	pinMode( RX_cont_RL2 , OUTPUT ) ;
	pinMode( TX_sw_RL , OUTPUT ) ;
	pinMode( CW_padle , OUTPUT ) ;
//	pinMode( AUX0_1 , OUTPUT ) ;
//	pinMode( AUX0_2 , OUTPUT ) ;
//	pinMode( AUX0_4 , OUTPUT ) ;
//	pinMode( AUX0_8 , OUTPUT ) ;
	pinMode( Stereo , OUTPUT ) ;
	pinMode( Reverse , OUTPUT ) ;
//	pinMode( DVKm1 , OUTPUT ) ;
//	pinMode( DVKm2 , OUTPUT ) ;
//	pinMode( DVKm3 , OUTPUT ) ;
//	pinMode( DVKm4 , OUTPUT ) ;

//	for Locked Rig Switching
	pinMode( Rig1PushSwPort , INPUT_PULLUP );
	pinMode( Rig2PushSwPort , INPUT_PULLUP ); 
	pinMode( StereoPushSwPort , INPUT_PULLUP ); 

//	for Arduino UNO Serial port

	Serial.begin( 9600 ) ;
	Serial.println( SO2R_name ) ;
	
	OTRSPcommand = "" ;
	Recived = false ;
	RxStatus = "RX1" ;
	TxStatus = "TX1" ;
	OldRxStatus = RxStatus ;
	OldTxStatus = TxStatus ;

	RX1_on() ; 
	TX1_on() ; 


//	for Locked Rig
	NowTimeRig1 = 0 ;
	NowTimeRig2 = 0 ;
	OldTimeRig1 = 0 ;
	OldTimeRig2 = 0 ;
	TimeRig1 =  0 ;
	TimeRig2 =  0 ;
	NowTimeStereo =  0  ;
	OldTimeStereo =  0  ;
	TimeStereo =  0 ;
	Rig1IsLocked = false ;
	Rig2IsLocked = false ;
	StereoIsLocked = false ;
	OccuredLocking = false ;
	Rig1PushSwStatus = HIGH ;
	Rig2PushSwStatus = HIGH ;
	StereoPushSwStatus = HIGH ;
	OldRigLockedStatus = false ;
	RigLockedStatus = false ;

// Initialization of LCD display
	lcd.begin(16, 2);
	lcd.clear() ;
	lcd.home() ;
	lcd.print( message00 );
	lcd.setCursor(0,1) ;
	lcd.print( " FW = ");
	lcd.print(FW );
	delay( 3000 ) ;
	lcd.clear() ;

}


//----------------------------------------------------
//
//
//
//----------------------------------------------------

void LockCheckRig1(){
/*
  Specification
  Rig 1 push button on and Rig 1 is Lock
  If you press the same button unlock
*/
	
/*
	仕様
		Rig1プッシュボタン　オンで　Rig1がLock
		同じボタンを押した場合にはロックを解除
*/

	Rig1PushSwStatus = digitalRead ( Rig1PushSwPort ) ;
	
	if( Rig1PushSwStatus == LOW ){
		NowTimeRig1 = millis() ;
		TimeRig1 = NowTimeRig1 - OldTimeRig1 ;
		if( TimeRig1 > GuardTime ) {
			Rig1IsLocked = !Rig1IsLocked ;
			Rig2IsLocked = false ;
			OldTimeRig1 = NowTimeRig1 ;
//			OldRxStatus = RxStatus ;
//			OldTxStatus = TxStatus ;
		}
	}
	if( Rig1IsLocked ) {
		RxStatus = "RX1" ;
		TxStatus = "TX1" ;
		RigLockedStatus = true ;
		OldRigLockedStatus = RigLockedStatus ;
	} else if( !Rig2IsLocked ){
		RigLockedStatus = false ;
		OldRigLockedStatus = RigLockedStatus ;
	}
}


void LockCheckRig2(){
/*
  Specification
    Rig 2 push button on and Rig 2 is Lock
    If you press the same button,a locked status transfer to a unlocked status.
*/
	
/*
	仕様
		Rig2プッシュボタン　オンで　Rig2がLock
		同じボタンを押した場合にはロックを解除
*/

	Rig2PushSwStatus = digitalRead ( Rig2PushSwPort ) ;
	
	if( Rig2PushSwStatus == LOW ){
		NowTimeRig2 = millis() ;
		TimeRig2 = NowTimeRig2 - OldTimeRig2 ;
		if( TimeRig2 > GuardTime ) {
			Rig2IsLocked = !Rig2IsLocked ;
			Rig1IsLocked = false ;
			OldTimeRig2 = NowTimeRig2 ;
//			OldRxStatus = RxStatus ;
//			OldTxStatus = TxStatus ;
		}
	}
	if( Rig2IsLocked ) {
		RxStatus = "RX2" ;
		TxStatus = "TX2" ;
		RigLockedStatus = true ;
		OldRigLockedStatus = RigLockedStatus ;
	} else if( !Rig1IsLocked ) {
		RigLockedStatus = false ;
		OldRigLockedStatus = RigLockedStatus ;
	}
}


void LockCheckStereo(){
/*
Specification
Operating conditions are force switch state (RigLockedStatus is true)
Stereo state with Stereo push button on
If you press the same button unlock
*/
	
/*
	仕様
		動作条件は、フォーススイッチ状態であること( RigLockedStatusがtrue )
		Stereoプッシュボタン　オンで　Stereo状態k
		同じボタンを押した場合にはロックを解除
*/

	StereoPushSwStatus = digitalRead ( StereoPushSwPort ) ;
	if ( RigLockedStatus ) {
		if( StereoPushSwStatus == LOW ){
			NowTimeStereo = millis() ;
			TimeStereo = NowTimeStereo - OldTimeStereo ;
			if( TimeStereo > GuardTime ) {
				StereoIsLocked = !StereoIsLocked ;
				OldTimeStereo = NowTimeStereo ;
			}
		}

	    // Change for mono to Stereo
		if( StereoIsLocked ) {
			if( Rig1IsLocked ) {
				if(RxStatus == "RX1"){
					RxStatus = "RX1S" ;
				} 
			}
			if( Rig2IsLocked ) {
				if(RxStatus == "RX2"){
					RxStatus = "RX2S" ;
				}
			}
		}
			
			
	    // change from Stereo to mono
		if( !StereoIsLocked ) {
			if(RxStatus == "RX1S"){
				RxStatus = "RX1" ;
			} 
			if(RxStatus == "RX2S"){
	 			RxStatus = "RX2" ;           
			}
			
		}
	}
}


// 	OTRSP SO2R Command Reciveing control function

void command_reciveing() {

// Command messege structure: QueryPrefix + Keyword + Item + Value + CR(hex 0D  Decimal 13)
// COMMAND reciveing

//	while ( !Recived ){
		if ( Serial.available() > 0 ) {
			byte buffer=Serial.read() ;
			if (OTRSPcommand.length() > 17 ) {				// Checking Recived Command Lengths 
				OTRSPcommand = "" ;
				Recived = false ;
//				break ;
				}
			if (buffer==0x0d) {				// When recived a CR code, start to analyze recived commnads.
				Recived = true ;
//				break ;
			}
			OTRSPcommand +=(char) buffer ;
		}
//	}
}

void OtrspBufferClear() {

	if (Serial.available() > 0) {
		for ( int i = 0 ; i < Serial.available() ; i++){
			byte TrushRecivedData = Serial.read() ;
		}
	}
	
//	for ( int i = 1 ; i < OTRSPlength ; i++){
//		if (Serial.available() > 0) {
//				byte TrushRecivedData = Serial.read() ;
//		}
//	}
	
	OTRSPcommand = "" ;
}


void command_handling(){

		if (OTRSPcommand.startsWith( "TX1" ) ) {
			TxStatus = "TX1" ;
			return ;
			} 
		if (OTRSPcommand.startsWith( "TX2" ) ) {
			TxStatus = "TX2" ;
			return ;
		}

		if (OTRSPcommand.startsWith( "RX1" ) ) {
			RxStatus = "RX1" ;
			if (OTRSPcommand.startsWith( "RX1S" ) ) {
				RxStatus = "RX1S" ;
				return ;
			}
			if (OTRSPcommand.startsWith( "RX1R" ) ) {
				RxStatus = "RX1R" ;
				return ;
			}
		}

		if ( OTRSPcommand.startsWith( "RX2" )   ) {
			RxStatus = "RX2" ;
			if  ( OTRSPcommand.startsWith( "RX2S" )  ) {
				RxStatus = "RX2S" ;
				return ;
			} 
			if  ( OTRSPcommand.startsWith( "RX2R" )  ) {
				RxStatus = "RX2R" ;
				return ;
			}
		}

		if (OTRSPcommand.startsWith( "AUX" ) ) {
			AuxStatus = OTRSPcommand ;
			return ;
		}

		if ( OTRSPcommand.startsWith( "KP1" )   ) {
			DVKStatus = "KP1" ;
			return ;
		}
		if ( OTRSPcommand.startsWith( "KP2" )   ) {
			DVKStatus = "KP2" ; 
			return ;
		}
		if ( OTRSPcommand.startsWith( "KP3" )   ) {
			DVKStatus = "KP3" ;
			return ;
		}
		if ( OTRSPcommand.startsWith( "KP4" )   ) {
			DVKStatus = "KP4" ; 
			return ;
		}


	//
	//		analyzing QUERY's command, and handling.
	//
	
	if ( OTRSPcommand.charAt(0) == '?' ){    
		if (OTRSPcommand.startsWith("?NAME")) {
			Serial.println ( SO2R_name) ; 
			return ;
		}
		else if (OTRSPcommand.startsWith("?FW")) {
			Serial.println ( FW ) ; 
			return ;
		}
		else if (OTRSPcommand.startsWith("?RX")) {
			Serial.println ( RxStatus ) ;
			return ;
		} 
		else if (OTRSPcommand.startsWith("?TX")) {
			Serial.println ( TxStatus ) ;
			return ;
		}
		else if (OTRSPcommand.startsWith("?KP")) {
//			Serial.println ( DVKStatus ) ;
			Serial.println ( "KP" ) ;
			return ;
		}
		// If recived only '?" query, this device reply also '?".
		else if (OTRSPcommand.length() == 2 ) {
			Serial.println ( "?" ) ;
			return ;
		}
		else {
			// When recived an unrecognized command Query,reply to send same command.
			Serial.println ( OTRSPcommand.substring(1) ) ;
			return ;
		}
	}
}

// ----------------------------------------	
//	device control functions
//-----------------------------------------	

void	DeviceControl(){

		if (RxStatus == "RX1" ){
			RX1_on() ;
					}
		else if (RxStatus == "RX1S" ){
			RX1S_on() ;
		}
		else if (RxStatus == "RX1R" ){
			RX1R_on() ;
		}
		else if (RxStatus == "RX2" ){
			RX2_on() ;
		}
		else if (RxStatus == "RX2S" ){
			RX2S_on() ;
		}
		else if (RxStatus == "RX2R" ){
			RX2R_on() ;
		}
	
		if (TxStatus == "TX1" ){
			TX1_on() ;
		}
		else if (TxStatus == "TX2" ){
			TX2_on() ;
		}
			
		if (AuxStatus.startsWith( "AUX" ) ) {
			aux1_output_handling() ;
		}

		if (DVKStatus == "KP1" ){
			KP1_OnOff() ;
			DVKStatus = "" ; 
		}

		else if (DVKStatus == "KP2" ){
			KP2_OnOff() ;
			DVKStatus = "" ; 
		}

		else if (DVKStatus == "KP3" ){
			KP3_OnOff() ;
			DVKStatus = "" ; 
		}
			
		else if (DVKStatus == "KP4" ){
			KP4_OnOff() ;
			DVKStatus = "" ; 
		}

		if ( RigLockedStatus ) {
			Locked();
		} else {
			UnLocked();
		}
}

//
//		SO2R device control functions
//

void Locked() {
	digitalWrite(CW_padle, HIGH) ;
}

void UnLocked() {
	digitalWrite(CW_padle, LOW) ;
}

void RX1_on() {
	digitalWrite(RX_cont_RL1, LOW) ;
	digitalWrite(RX_cont_RL2, LOW) ;
	digitalWrite(Stereo, LOW) ;
//	digitalWrite(Reverse , LOW) ;
	} 

void RX1S_on(){
	digitalWrite(RX_cont_RL1, HIGH) ;
	digitalWrite(RX_cont_RL2, LOW) ;
	digitalWrite(Stereo , HIGH) ;
//	digitalWrite(Reverse , LOW) ;
	}

void RX1R_on(){
	digitalWrite(RX_cont_RL1, LOW) ; 
	digitalWrite(RX_cont_RL2, HIGH) ; 
	digitalWrite(Stereo , LOW) ; 
//	digitalWrite(Reverse , HIGH) ; 
	}

void RX2_on(){
	digitalWrite(RX_cont_RL1, HIGH) ; 
	digitalWrite(RX_cont_RL2, HIGH) ;
	digitalWrite(Stereo , LOW) ; 
//	digitalWrite(Reverse , LOW) ;
	}

void RX2S_on(){
	digitalWrite(RX_cont_RL1, HIGH)  ;
	digitalWrite(RX_cont_RL2, LOW) ;
	digitalWrite(Stereo , HIGH) ; 
//	digitalWrite(Reverse , LOW) ;
	}

void RX2R_on(){
	digitalWrite(RX_cont_RL1, LOW) ;
	digitalWrite(RX_cont_RL2, HIGH) ;
	digitalWrite(Stereo , LOW) ; 
//	digitalWrite(Reverse , HIGH) ;
	}

void TX1_on() {
	digitalWrite(TX_sw_RL, LOW ) ;
	} 

void TX2_on(){
	digitalWrite(TX_sw_RL, HIGH ) ;
	}
	
void KP1_OnOff(){
	digitalWrite(DVKm1, HIGH ) ;
	delay(100) ;
	digitalWrite(DVKm1, LOW ) ;
	}

void KP2_OnOff(){
	digitalWrite(DVKm2, HIGH ) ;
	delay(100) ;
	digitalWrite(DVKm2, LOW ) ;
	}
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
void loop() {
	
//  Scan Locked Switches
	
	LockCheckRig1() ;
	LockCheckRig2() ;
	LockCheckStereo() ;

//    Locked Manual mode
	
	if ( RigLockedStatus ) {
		DeviceControl() ;
		LcdDisplayLockedSo2r() ; 
		OtrspBufferClear() ;
	}
	
//   OTRSTP protocol mode
	
	if ( !RigLockedStatus ) {
		//DeviceControl() ;
		LcdDisplaySo2r() ;
		
		command_reciveing() ;	// When reciveing command, executing the below function.
		if ( Recived ){
			command_handling() ;
			DeviceControl() ;
			LcdDisplaySo2r() ;
			OTRSPcommand = "" ;
			Recived = false ;
		}
	}

}


/*


GNU GENERAL PUBLIC LICENSE
Version 3, 29 June 2007
Copyright © 2007 Free Software Foundation, Inc. <http://fsf.org/>
Everyone is permitted to copy and distribute verbatim copies of this license document, but changing it is not allowed.
Preamble
The GNU General Public License is a free, copyleft license for software and other kinds of works.
The licenses for most software and other practical works are designed to take away your freedom to share and change the works. By contrast, the GNU General Public License is intended to guarantee your freedom to share and change all versions of a program--to make sure it remains free software for all its users. We, the Free Software Foundation, use the GNU General Public License for most of our software; it applies also to any other work released this way by its authors. You can apply it to your programs, too.
When we speak of free software, we are referring to freedom, not price. Our General Public Licenses are designed to make sure that you have the freedom to distribute copies of free software (and charge for them if you wish), that you receive source code or can get it if you want it, that you can change the software or use pieces of it in new free programs, and that you know you can do these things.
To protect your rights, we need to prevent others from denying you these rights or asking you to surrender the rights. Therefore, you have certain responsibilities if you distribute copies of the software, or if you modify it: responsibilities to respect the freedom of others.
For example, if you distribute copies of such a program, whether gratis or for a fee, you must pass on to the recipients the same freedoms that you received. You must make sure that they, too, receive or can get the source code. And you must show them these terms so they know their rights.
Developers that use the GNU GPL protect your rights with two steps: (1) assert copyright on the software, and (2) offer you this License giving you legal permission to copy, distribute and/or modify it.
For the developers' and authors' protection, the GPL clearly explains that there is no warranty for this free software. For both users' and authors' sake, the GPL requires that modified versions be marked as changed, so that their problems will not be attributed erroneously to authors of previous versions.
Some devices are designed to deny users access to install or run modified versions of the software inside them, although the manufacturer can do so. This is fundamentally incompatible with the aim of protecting users' freedom to change the software. The systematic pattern of such abuse occurs in the area of products for individuals to use, which is precisely where it is most unacceptable. Therefore, we have designed this version of the GPL to prohibit the practice for those products. If such problems arise substantially in other domains, we stand ready to extend this provision to those domains in future versions of the GPL, as needed to protect the freedom of users.
Finally, every program is threatened constantly by software patents. States should not allow patents to restrict development and use of software on general-purpose computers, but in those that do, we wish to avoid the special danger that patents applied to a free program could make it effectively proprietary. To prevent this, the GPL assures that patents cannot be used to render the program non-free.
The precise terms and conditions for copying, distribution and modification follow.
TERMS AND CONDITIONS
0. Definitions.
“This License” refers to version 3 of the GNU General Public License.
“Copyright” also means copyright-like laws that apply to other kinds of works, such as semiconductor masks.
“The Program” refers to any copyrightable work licensed under this License. Each licensee is addressed as “you”. “Licensees” and “recipients” may be individuals or organizations.
To “modify” a work means to copy from or adapt all or part of the work in a fashion requiring copyright permission, other than the making of an exact copy. The resulting work is called a “modified version” of the earlier work or a work “based on” the earlier work.
A “covered work” means either the unmodified Program or a work based on the Program.
To “propagate” a work means to do anything with it that, without permission, would make you directly or secondarily liable for infringement under applicable copyright law, except executing it on a computer or modifying a private copy. Propagation includes copying, distribution (with or without modification), making available to the public, and in some countries other activities as well.
To “convey” a work means any kind of propagation that enables other parties to make or receive copies. Mere interaction with a user through a computer network, with no transfer of a copy, is not conveying.
An interactive user interface displays “Appropriate Legal Notices” to the extent that it includes a convenient and prominently visible feature that (1) displays an appropriate copyright notice, and (2) tells the user that there is no warranty for the work (except to the extent that warranties are provided), that licensees may convey the work under this License, and how to view a copy of this License. If the interface presents a list of user commands or options, such as a menu, a prominent item in the list meets this criterion.
1. Source Code.
The “source code” for a work means the preferred form of the work for making modifications to it. “Object code” means any non-source form of a work.
A “Standard Interface” means an interface that either is an official standard defined by a recognized standards body, or, in the case of interfaces specified for a particular programming language, one that is widely used among developers working in that language.
The “System Libraries” of an executable work include anything, other than the work as a whole, that (a) is included in the normal form of packaging a Major Component, but which is not part of that Major Component, and (b) serves only to enable use of the work with that Major Component, or to implement a Standard Interface for which an implementation is available to the public in source code form. A “Major Component”, in this context, means a major essential component (kernel, window system, and so on) of the specific operating system (if any) on which the executable work runs, or a compiler used to produce the work, or an object code interpreter used to run it.
The “Corresponding Source” for a work in object code form means all the source code needed to generate, install, and (for an executable work) run the object code and to modify the work, including scripts to control those activities. However, it does not include the work's System Libraries, or general-purpose tools or generally available free programs which are used unmodified in performing those activities but which are not part of the work. For example, Corresponding Source includes interface definition files associated with source files for the work, and the source code for shared libraries and dynamically linked subprograms that the work is specifically designed to require, such as by intimate data communication or control flow between those subprograms and other parts of the work.
The Corresponding Source need not include anything that users can regenerate automatically from other parts of the Corresponding Source.
The Corresponding Source for a work in source code form is that same work.
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

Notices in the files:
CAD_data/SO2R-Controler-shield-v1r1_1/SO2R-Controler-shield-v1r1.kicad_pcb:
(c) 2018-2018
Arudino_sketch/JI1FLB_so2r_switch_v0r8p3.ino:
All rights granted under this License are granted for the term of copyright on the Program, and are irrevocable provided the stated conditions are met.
